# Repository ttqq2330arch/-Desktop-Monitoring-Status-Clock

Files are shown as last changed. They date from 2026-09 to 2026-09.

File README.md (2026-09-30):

# 桌面电脑状态监控 · PC 小屏

ESP32-WROOM-32 DevKit V1（CH340C）+ ST7735S 128×160 横放（逻辑 160×128）。
PC 端采集本机状态 → USB 串口 1Hz 推 JSON → ESP32 负责显示。

三页：**总览 / 大时钟 / 天气**，单个按键 GPIO13 循环切换；PC 在线时三页每 10 秒自动轮播。

**★ 脱离电脑也能当钟用**：设备自带 2.4G WiFi + SNTP 对时，不接电脑时会自动进时钟页
并显示**正确时间**（不再是一块显示「NO DATA」的砖）。配置见「二 · 6 不接电脑也能用」。
总览页与天气页的数据仍来自 PC。

**状态：固件已编译通过（2026-09-19，931,536 B / Flash 70.6% / RAM 16.3%，0 warning；
已删除日历页、新增三页 10 秒自动轮播、新增 WiFi 独立对时）。**

<p align="center">
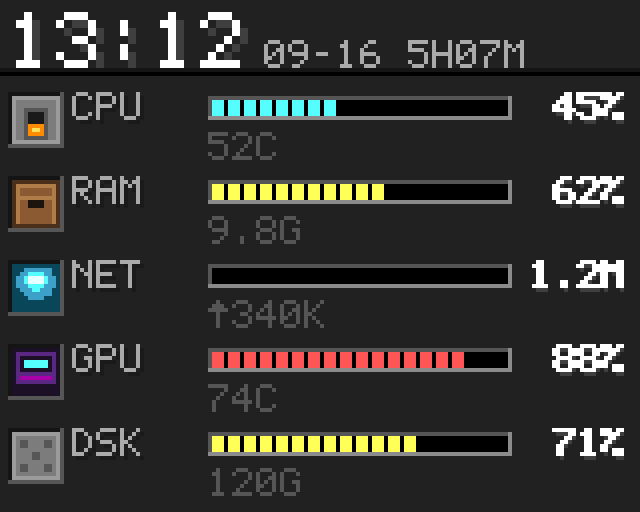
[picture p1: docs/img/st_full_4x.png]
  
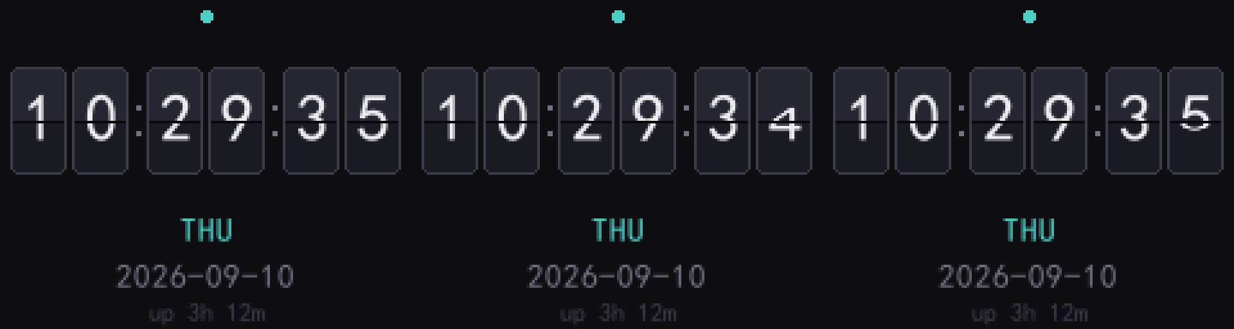
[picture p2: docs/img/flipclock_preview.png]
  
</p>
<p align="center"><sub>
状态页（四环仪表）　｜　翻页时钟
</sub></p>

<p align="center">
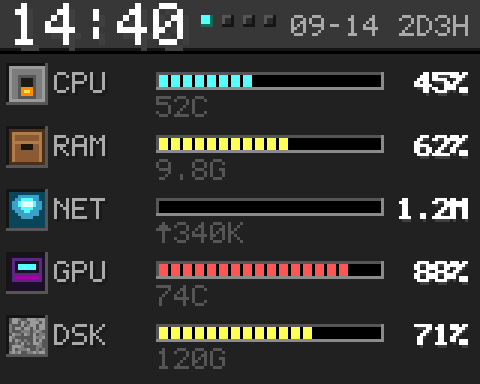
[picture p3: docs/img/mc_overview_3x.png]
  
  
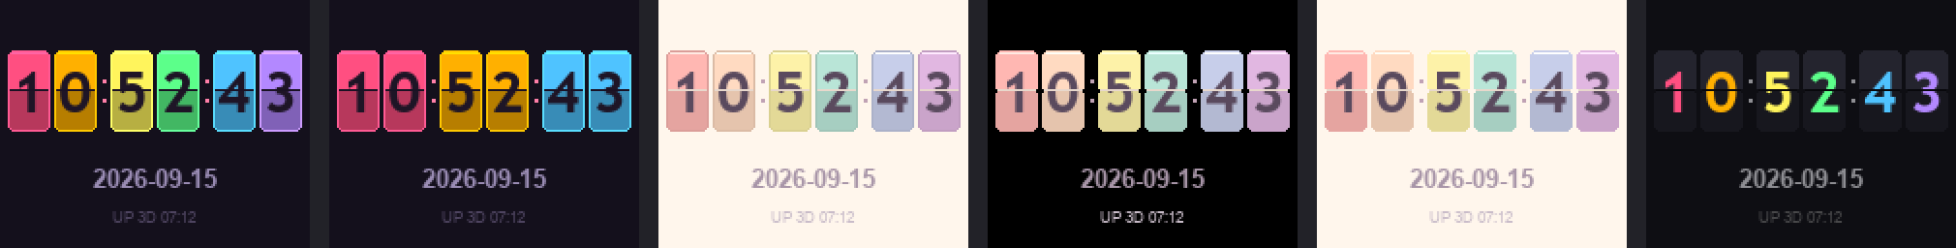
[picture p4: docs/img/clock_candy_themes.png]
  
</p>
<p align="center"><sub>
总览 · 3x 放大　｜　磁盘方块图标细节　｜　时钟配色备选
</sub></p>

更多设计稿在 `docs/img/`，全部由 `esp32/tools/` 下的生成器离线产出。

---

## 一、接线

| ST7735S | ESP32 | 说明 |
|---|---|---|
| VCC | 3.3V | **不要接 5V** |
| GND | GND | |
| SCL / SCK | GPIO18 | VSPI 时钟 |
| SDA / MOSI | GPIO23 | VSPI 数据 |
| CS | GPIO5 | 片选 |
| DC / A0 | GPIO17 | 数据/命令 |
| RES / RST | GPIO16 | 复位 |
| BLK | GPIO4 | 背光，LEDC PWM 调光（默认 78%） |
| MISO | 不接 | |

按键：**GPIO13 → GND**（内部上拉），短按切页（并重置 10 秒轮播计时），长按 >600ms 切换时钟页数字字体。

接线示意图见 [`docs/接线图.svg`](docs/接线图.svg)（SVG，浏览器可直接打开）。

引脚定义在 `esp32/src/main.cpp` 顶部的 `PIN_*`。

> 避开的引脚：6~11（SPI Flash）、34~39（input-only）、0/2/12/15（strapping）。

---

## 二、跑起来

### 1. 编译烧录

```bat
cd esp32
pio run -t upload
```

首次编译会自动下载 LovyanGFX 与 ArduinoJson、PubSubClient（约 130 MB，只需一次）。

**烧录前必须关掉采集脚本**——CH340C 在 DevKit V1 上硬接 UART0，脚本独占 COM 口时
PlatformIO 抢不到端口：

```bat
cd ..\pc
python stop_monitor.py     :: 建 pause.flag + 杀采集进程
```

**不想搭编译环境？** `esp32/firmware_prebuilt/` 里有与源码同版本的固件四件套
（含 md5 与烧写偏移说明），用 esptool 一条命令直烧即可。注意：工程使用**自定义
3MB app 分区表**（`esp32/partitions.csv`，离线局域网轮询的 flash 前提），
无论哪种烧法都必须连 `partitions.bin` 一起烧，单烧 app 会因分区不一致而异常。

### 2. 装依赖并启动采集

```bat
pip install psutil pyserial nvidia-ml-py
cd pc
python monitor.py --list        :: 看串口号
python monitor.py               :: 自动扫 CH340
python monitor.py --port COM6   :: 手动指定
python monitor.py --dry-run     :: 只打印 JSON 不下发，调试用
```

### 3. 开机自启 + USB 看门狗

**插上 USB 就自己跑，不用管时机。** 靠两级配合：

| 层 | 是什么 | 干什么 |
|---|---|---|
| 任务计划 `PCMonitorWatch` | 登录时启动 `watcher.py` | 只负责让看门狗活着 |
| USB 看门狗 `watcher.py` | 常驻，每 3 秒扫一次串口 | 看到 CH340 就把 `monitor.py` 拉起来 |

**为什么不直接让任务计划启动 `monitor.py`**：登录瞬间 USB 常常还没枚举完，
那个时点启动是赌运气。看门狗不看时机看硬件——开机时已经插着、还是后来才插、
拔了再插，它都能接管。

任务计划参数：触发器 `AtLogOn`、错过补跑 `StartWhenAvailable`、
失败重启最多 3 次（间隔 1 分钟）、运行时限无限制、全程无窗口。

**为什么用任务计划而不是注册表 Run 键**：Run 键只能"到点跑一次"，跑了就死了没人管；
任务计划能错过补跑、失败重启，而且进程由 `svchost` 托管，更稳。

实测三条行为（都验过）：

- 采集进程被杀 → 3 秒内看门狗自动拉起，屏 5 秒内恢复
- 拔掉开发板 → 看门狗不动作，`monitor.py` 自己等 USB 回来重连（避免抖动误杀）
- 有 `pause.flag` → 看门狗让路不拉起（烧录用）

其他关键点：

- **用 `pythonw` 而不是 `python`**：GUI 子系统程序，天生没有控制台窗口。
  代价是 `pythonw` 没有 stdout，脚本已内置兜底，把输出写进 `pc/monitor.log`。
- **不要包一层 `cmd.exe /c`**：cmd 是控制台程序，登录时会闪一下黑窗口。
- **不要加 VBS / `wscript` 中间层**：本机安全策略把 `wscript.exe` 当 LOLBin 拦截。
- **脚本自带单实例保护**：已有实例在跑时新启动的直接退出，不会多实例抢同一个串口。
- **判断采集在不在跑用端口锁（47651），不扫进程**——扫进程在 pythonw 下
  会把启动中的自己误判成目标，之前踩过。看门狗自己的锁是 47652。
- 采集起来后屏会在 1 秒内从 `PC MONITOR` 跳到数据界面。

安装 / 卸载（**换电脑、重装系统后跑一次就行**）：

```bat
install.bat                    :: 双击。自动找 Python、装依赖、注册任务、启动
python install.py --check      :: 只体检，不改任何东西
python install.py --uninstall  :: 卸载计划任务
```

`install.py` 会做四件事：找解释器（优先无窗口的 `pythonw`）→ 补依赖
（`psutil` / `pyserial`，缺就自动 `pip install`，装不上会退回 `--user`）
→ 注册计划任务 → 启动并回报任务状态。

**路径全是动态探测的**，没有写死用户名和盘符，拷贝整目录到任何一台 Windows
都能用。看门狗拉起采集脚本时也用自己所在的解释器，不会去找某个固定路径。

日常启停：

```bat
python stop_monitor.py     :: 停止采集（烧录固件前必做）
start_monitor.bat          :: 双击，恢复推送
```

**烧录固件的标准流程**（顺序不能反）：

```bat
python stop_monitor.py     :: 创建 pause.flag + 杀采集进程
pio run -t upload          :: 烧录（此刻 COM 口是空的）
start_monitor.bat          :: 删掉 pause.flag，看门狗几秒内自动恢复推送
```

`stop_monitor.py` 必须先建 `pause.flag` 再杀进程——只杀进程的话，
看门狗 3 秒内就把脚本拉回来，COM 口又被抢走，烧录必然失败。

> 脚本版和便携版**任选一种，别同时装**。便携版的日志在
> `pc\dist\pc-monitor-portable\` 下，不在 `pc\` 下——排查时别翻错目录。

### 4. 换到另一台电脑

ESP32 固件在板上，**不用重烧**。要搬的只有 PC 端。按那台电脑有没有 Python 分两条路。

#### 4A. 没装 Python（推荐，零依赖）—— 用免安装便携版

```bat
:: 1. 把 pc\dist\pc-monitor-portable 整个文件夹拷过去（U 盘都行，约 16 MB）
:: 2. 双击「安装.bat」
:: 3. 插上 ESP32，几秒内屏幕离开 PC MONITOR
```

> `pc/dist/` 不入库（见 `.gitignore`），先用 `build_portable.py` 在本机打一次包。

目录里就这些东西（详细看里面的 `使用说明.txt`）：

| 文件 | 作用 |
|---|---|
| `monitor.exe` | 采集端，每 1 秒把状态推给小屏 |
| `watcher.exe` | 看门狗，每 3 秒扫串口，见到 CH340 就拉起采集端 |
| `安装.bat` / `卸载.bat` | 注册 / 删除计划任务 |
| `暂停采集.bat` / `恢复采集.bat` | 烧录固件前暂停，烧完恢复 |
| `watcher.log` / `monitor.log` | 出问题时先看这两个 |

重新打包（改过脚本之后必须重打，否则 exe 里还是旧逻辑）：

```bat
python build_portable.py     :: 需要 PyInstaller：pip install pyinstaller
```

#### 4B. 装了 Python 3.8+（勾了 Add Python to PATH）—— 用脚本版

```bat
:: 1. 把整个 pc 目录拷过去
:: 2. 双击 install.bat
::    它会自动：找 Python -> 装 psutil/pyserial -> 注册计划任务 -> 启动看门狗
:: 3. 插上 ESP32，几秒内屏幕离开 PC MONITOR
python install.py --check    :: 想先体检就跑这个，不改任何东西
```

两条路共用的几个已处理掉的坑：

- **路径不写死**：原来硬编码了某台机器的 PlatformIO 解释器绝对路径，
  换台机器必然失效。现在脚本版运行时探测解释器，打包版用 exe 自身位置定位。
- **串口号不写死**：自动扫 CH340（VID `1A86`），换台电脑分到 COM3 还是 COM9 都能连。
- **两台电脑别同时插**：板子只有一个串口，两台都跑采集会互相抢。

打包这件事有几个坑，都处理了，重新打包时别改回去：

- **必须用 `--windowed`**：常驻程序不能有控制台窗口，否则桌面一直挂黑框。
  windowed 模式下 `sys.stdout` 为 None，脚本已兜底把输出写进日志文件。
- **日志路径不能用 `__file__`**：打包成单文件 exe 后 `__file__` 指向临时解压目录
  （`_MEIPASS`），日志会写进去然后随进程退出丢失。两个脚本统一用 `app_dir()`——
  frozen 时取 `sys.executable` 所在目录，保证日志落在 exe 旁边。
- **看门狗要直接拉 `monitor.exe`**：打包后没有解释器可调用，`watcher.py` 里
  按 `sys.frozen` 判断，frozen 时执行同目录的 `monitor.exe`。
- **中间产物放纯 ASCII 目录**：`build_portable.py` 把 work/spec 丢到 `%TEMP%`，
  打完再拷回来——中文路径下 PyInstaller 容易出幺蛾子。
- **进程列表里一个实例显示两个 PID**：PyInstaller 单文件模式是「bootloader 父进程
  + 真子进程」，不是双开。脚本版同理（venv 包装器 + 真解释器）。
- **必须用带 PyInstaller 的那个解释器跑**：`build_portable.py` 开头会自检，
  没装 PyInstaller 会直接退出并提示。

### 5. 屏停在 PC MONITOR 怎么排查

`PC MONITOR` 是**等待态**，只说明一件事：ESP32 没收到串口数据。跟屏幕几何、
固件渲染都没关系，别去动 `OFFSET_X/Y`。

按顺序查：

1. **看门狗活着吗** —— 任务 `PCMonitorWatch` 的 `State` 应该是 `Running`，
   用 `schtasks /query /tn PCMonitorWatch` 查；不是就重跑 `install.bat`。
2. **看 `pc/watcher.log`** —— 每 3 秒扫一次，状态变化才记一行：
   - `CH340=未连接` → 线没插好或驱动没装，先看设备管理器。
   - `CH340=COM6 暂停=否 采集=未运行` 却没跟着出现「拉起采集脚本」→ 看门狗卡了，重启任务。
   - `暂停=是` → 有 `pause.flag` 忘了删（烧录后没跑 `start_monitor.bat`）。
3. **看 `pc/monitor.log` 最后几行**：
   - 没有 `[LAUNCH]` 痕迹 → 采集没被拉起，看上一条。
   - 有 `[LAUNCH]` 但没 `[串口] 已连接` → 卡在等 CH340，检查 USB 线和驱动。
   - 有 `[崩溃]` → 下面就是 traceback，照着修。
4. **COM 口被别的程序占了** —— 串口监视器、Arduino IDE 串口绘图仪、`handle64.exe -a Serial` 都能看出来。
5. 烧录固件前必须 `python stop_monitor.py`，否则 PlatformIO 抢不到 COM 口。

### 6. 不接电脑也能用（WiFi 独立对时）

设备插充电头独立供电时，会自动进时钟页并联网取标准时间 —— 不再是「NO DATA」砖。

**首次配置**（只需一次；凭据写进设备 NVS，**不随固件、不进仓库**）：

```
python pc/stop_monitor.py                 # 先让出串口
（用任意串口工具连 COM7 @115200，逐行发送：）
WIFI:你的SSID,你的密码                     # 可发两组（主 / 备用路由器）
NET?                                      # 查看当前状态
```

写完直接拔线插充电头即可。上电 3 秒后开始尝试连接，**拿到时间立刻关掉 WiFi**。

**注意**

- ESP32-WROOM-32 **只支持 2.4G**，路由器的 5G 名字连不上（双频合一通常没问题）。
- 凭据存 NVS，**源码里没有任何 WiFi 密码** —— 这是为 `export_opensource.py` 导出时不泄露。
- 最多记住 2 组，按顺序尝试；换路由器重发 `WIFI:` 即可覆盖；`WIFICLR` 清空全部。
- 没有网络时可用串口手动对时：`TIME:2026-09-19 13:40:00`（重启即失效，仅作兜底）。
- 屏上状态词（时钟页卡片下方）：`NO CFG` 未配置 / `LINKING` 连接中 / `SYNCING` 对时中 /
  `WIFI OK` 已对时 / `NO NET` 连不上 / `NO TIME` 有凭据但还没对上。
- 串口心跳可直接看到设备自己的时间：`[HB] view=1 rx=.. net=WIFI OK t=13:52:03 heap=..`。

---

## 三、屏幕不对，改这几个常量

都在 `esp32/src/main.cpp` 顶部，别的地方不要动。

| 现象 | 改哪个 |
|---|---|
| 有白边 / 画面偏移 | `OFFSET_X`（现 0）、`OFFSET_Y`（现 0） |
| **整屏画面倾斜** | panel 配置里的 `cfg.memory_width`，现 **130**（用库默认 132 就会斜） |
| 红蓝颜色反了 | `RGB_ORDER` → `true` |
| 整屏发黑或发白 | `INVERT_COL` → `true` |
| 花屏 | `SPI_FREQ` 从 `20000000` 降到 `10000000` |
| 屏幕装反了（外壳倒装） | `PANEL_FLIP_180` → `1`（软件逐像素翻转 180°，见下节） |

`cfg.memory_width` 不在顶部常量区，它在 `LGFX` 构造函数的 `_panel.config(cfg)` 块里，
搜 `CFG5` 注释就能找到（那组几何参数是实测轮播挑出来的，别改回默认）。

改完重新 `pio run -t upload`。

### 关于 `PANEL_FLIP_180`（屏幕倒装）

外壳如果把它装反了，把 `PANEL_FLIP_180` 改成 `1` 即可，**别处不用动**。
实现是每帧画完后把整块精灵缓冲做一次逐像素 180° 翻转（行序倒置 + 行内像素倒置），
只搬 16bit 元素、不拆字节，所以 `swap565` 语义不变、不需要额外换字节序。

**为什么不直接用 `setRotation(3)`**：这块 ST7735S 的非标准几何（GRAM 132×162 /
可视 128×160）在 rotation 1 与 rotation 3 下的地址窗口无法对齐，实测两组参数都失败
（先是对角线错位，再是顶部一条乱码）。像素级翻转不触碰地址窗口与 MADCTL，
原理上不会出现错位。

翻转后**逻辑坐标与屏幕视觉是反的**，两件事必须记住：

- 逻辑 y 小 → 物理 y 大 → **屏幕视觉的下方**。屏幕最下方同时是 SPI 写入起点与
  面板扫描起点，两者同向同速，1Hz 整屏刷新时这一带撕裂最重。
- 所以：**每秒变化的高对比内容（时钟、日期）绝不能放在逻辑顶边**。
  两端各留一条静态纯背景带（`EDGE_TOP` / `EDGE_BOT`）就是为了这个——
  端点行每帧恒定，撕裂发生在端点也看不见。
- 幕布过渡要画在**逻辑右侧**，屏上才出现在左侧。

别试图用"每帧把端点行涂成背景色/复制邻行"来补——试过两版都反而露出横线或
把图标底行搬进撕裂带。**结构上留出静态带是唯一可靠的解法。**

---

## 四、显示内容

三页，**单个按键 GPIO13** 循环切换，或 **PC 在线时每 10 秒自动轮播**（切后在本页停留 10 秒，三页循环）。170ms 幕布过渡、1s 刷新、静态不闪烁。

> 自动轮播只在 **PC 在线**时生效。PC 关机 / 断流超过 5 秒后停在时钟页当钟用，不再轮播
> —— 否则会轮流停在总览 / 天气页显示「未连接」。手动短按切页会把 10 秒计时清零重算。

| 页 | 内容 |
|---|---|
| 0 OVERVIEW | 四环仪表：CPU / RAM / NET / GPU 四环 + 顶部时钟 + 右侧日期（蓝=正常，≥80% 整环转红） |
| 1 CLOCK | 彩虹电子时钟：六位糖果色数字 + 日期 + 开机时长；PC 断流 5s 后离线自走时 |
| 2 WEATHER | 城市 + 彩虹环温（弧长=当日高低温区间位置）+ 环内糖果温度 + 高低温 / 湿度 / 风速 |

> 原「整面月视图」日历页已于 2026-09-19 删除（页面数 4 → 3）。

顶栏：时间 + 日期 + 开机时长 + 页码方块。断流 5 秒后日期区显示 `OFF`。

### 1 · 总览页（《我的世界》主题）

色值与结构取自 MC 的 GUI 设计语言：16 色格式化调色板、GUI 灰阶、经验条绿 `#80FF20`。
三条结构规则比色值更关键——**立体边框**（凸=上/左亮、下/右暗；凹反过来）、
**文字右下 1px 投影**、**方块图标嵌物品栏凹槽**。

| 行 | 方块图标 | 条色 | 主值 | 副值 |
|---|---|---|---|---|
| CPU | 熔炉（石框 + 橙火） | §b 青 | 占用 % | 温度 |
| RAM | 箱子（棕木 + 锁扣） | §6 金 | 占用 % | 已用 GB |
| NET | 信标（青宝石） | §9 蓝 | ↓下行速率 | ↑上行速率 |
| GPU | 附魔台（紫 + 符文） | §d 品红 | 占用 % | 温度 |
| DSK | 石头（石块纹理） | §a 绿 | 占用 % | 剩余 GB |

字体是 **5×7 点阵（44 字形）**，本页内容全 ASCII，**不需要中文字库**——
比下面那几套汉字字模轻得多。数据链路：

```
tools/mc_ui_preview.py   设计稿生成器（零第三方依赖，出 1x / 3x / 局部放大 / 字形表 PNG）
        │  import
        ▼
tools/gen_mc_theme.py    导出 src/mc_theme.h（PROGMEM 位图 + 绘制函数），
        │                自带「写出的 C 文本重新解析回来逐值比对」校验
        ▼
   src/mc_theme.h        5×7 字形 / 12×12 方块图标 / mcStr / mcBevel / mcXpBar
```

改设计稿后重跑 `gen_mc_theme.py` 即可（`python gen_mc_theme.py`，日志落 `gen_mc_theme.log`），
**不要手改 `mc_theme.h`**，否则下次生成会覆盖。

排版验证另有一个只读工具 `tools/st_layout_preview.py`：用与固件相同的常量
（`EDGE_TOP` / `BODY_TOP` / `ROW_H`）重画一遍状态页，改版式前先看它，4x 放大出图。

### 2 · 中文点阵字库（天气页用）

内置字体无中文，三套互相隔离的 PROGMEM 字模（都是 SimHei 16×16 生成，
**仓库只含生成出的位图数组，不含字体文件**，见 `THIRD_PARTY.md`）：

| 文件 | 字数 | 生成脚本 | 用途 |
|---|---|---|---|
| `src/cn_font.h` | 12 | `tools/gen_cnfont.py` | **已停用**（原日历标题 年 / 月 / 一~十）；文件保留备用 |
| `src/weather_cn.h` | 34 | `tools/gen_weather_cn.py` | 天气词（晴 / 阴 / 雨 / 高 / 低 / 湿…） |
| `src/cn_city.h` | 199 | `tools/gen_city_cn.py` | 城市地名（省会 + 主要地级市 + 汉江/秦巴一带） |

排版铁律：双字标签占 2×(16+2)=36px，必须用 `cnStrW()` **真测宽**推进——
按单字宽 18px 推会让数字压在字上。字库缺字时 `wcnFind` 返 -1，整段不渲染。

**CPU 温度默认 `--`**：Windows 上没有管理员权限读不到，代价不值。
想开的话：`python monitor.py --temp`，需要管理员 + 把 `LibreHardwareMonitorLib.dll`
放到脚本同目录。

**GPU 非 N 卡显示 `--`**：A 卡和 Intel 核显在 Windows 上没有干净的读取接口。

### 3 · 时钟页（含离线走时）

HH MM SS 六张卡片式数字，每位数从 Candy Rainbow 调色板依次取色，
翻页动画由 `gStretch` 控制拉伸程度。

数字不是内置字体，而是 **4-bit alpha 掩码**（0..15 覆盖度），由
`tools/gen_clock_font.py` 用「超采样 SS=4 渲染 → 形态学膨胀加粗 → LANCZOS 降采样
→ 4bit 量化」烘焙而来——加粗做在超采样大图上，所以加粗后边缘仍然抗锯齿。
内置 4 套字体，**长按按键 >600ms 现场切换**。改字体或粗细后重跑生成器，
它自带触边自检（数字左右必须各留 ≥1px，否则报 `⚠`）。

**离线走时 + 自动对时**：PC 关机 / 断流超过 5 秒，设备自动跳到时钟页当钟用。
时间来源按优先级三级（配置见「二 · 6 不接电脑也能用」）：

1. **PC 在线** —— 串口每帧带真实时间，逐帧对齐，零漂移；
2. **PC 不在线** —— 设备自己连 2.4G WiFi 走 SNTP 取一次标准时间，之后由内部时钟自走，
   每 6 小时重校一次（**拿到时间立刻关 WiFi**，不干扰 SPI 刷屏、也不费电）；
3. **取不到时间** —— 继续用内部时钟，屏上给出状态词（`NO NET` / `NO CFG`）。

内部走时取决于 ESP32 的 40MHz 晶振（±10~40ppm），一天偏差数秒内，看时间够用。
**从来没有时间源**时（刚上电且未联网），时钟页显示六张空卡片 + 横杠占位 + 状态词，
不会退化成一块「NO DATA」。

### 4 · 天气页

`pc/monitor.py` 在 PC 侧拉天气，把结果随状态一起推进固件 —— 天气数据始终由 PC 提供。
（ESP32 自身只在「没有 PC 时间源」时短暂联网做 NTP 对时，不负责抓天气。）

配置在 `pc/weather_tune.json`（仓库给的是 `weather_tune.example.json`，
复制改名即可），可写死城市，也可以 `auto_location` 走 IP 定位。

几个已经踩过的坑，改这块前先读：

- **中文城市名与坐标必须同源。** 先用国内源（pconline）拿到中文城市名，
  再用 Open-Meteo 的 geocode 取该城市的坐标；`ipinfo.io` 只做兜底，
  且它的英文名必须能被内置 `CITY_ZH` 表识别才采纳其坐标。
  早期把「ipinfo 的坐标 + pconline 的中文名」拼在一起，屏上显示出「安康」
  而温度是另一个城市的——地名和天气对不上，就是这么来的。
- **网络出口直连优先。** 如果系统装了代理软件但没启动，
  Windows 下 `urllib.getproxies()` 会读到注册表里的代理地址，
  把所有请求发往一个没人监听的端口，四个天气源会全挂。
  `monitor.py` 里 `_open()` 显式用 `ProxyHandler({})` 先直连、失败才回落代理，
  日志会打一行 `[天气] 网络出口：直连`。
- **结果落盘缓存** `weather_cache.json`：看门狗重启 monitor 时先用缓存顶住，
  断网也不至于显示「无数据」。
- **失败退避重试** 30s→60s→…→300s，开机时网络往往还没就绪，这一步很关键。
- **城市名回退字段必须是纯 ASCII**：设备端中文缺字时用 ASCII 字库渲染它，
  所以 `monitor.py` 会用 `CITY_EN` 把中文城市名转成拼音（安康 → ANKANG）。

### 5 · 打印机页 ×2（双源：串口 / 局域网直连，互不干涉）

第 4、5 页显示两台 3D 打印机的实时状态（热端/热床温度、打印进度、文件名）。
数据来源由「PC 是否在线」单一门控，两路天然互斥：

- **PC 在线** → 走串口：`pc/printers.py` 在 PC 侧轮询打印机，随状态帧一起推给固件。
  Creality 走局域网 Moonraker（:7125），Anycubic 走打印机局域网 MQTT
  （Kobra X :18910 发现 → :9883 MQTT-TLS，凭据 AES-128-CBC 解密）。
- **PC 离线** → 固件自己用 WiFi 直连打印机（`src/printerlan.cpp`），
  打印机页照常显示，屏幕在「时钟 + 已配置打印机页」间轮播。

打印机 IP 配置三入口（NVS 断电保留）：

1. 串口命令：`PRN:槽位,类型,IP[,名称]`（槽 0=Creality/类型 0，槽 1=Anycubic/类型 1）、
   `PRNCLR` 清空、`PRN?` 查询；
2. 设备网页配置页「离线局域网打印机」卡片；
3. 已存 NVS 时断电重启自动生效。

设备状态接口 `http://<设备IP>/api/status` 里每台打印机带 `"src": "PC"/"LAN"`
字段，可直接验证当前数据来源。

---

## 五、仓库结构

```
esp32/
  platformio.ini          工程配置（依赖走 lib_deps 自动下载）
  partitions.csv          自定义分区表：app 3MB（离线 LAN 轮询的 flash 前提）
  no_map.py               摘掉 -Wl,-Map，绕开中文路径导致链接失败（见第七节）
  firmware_prebuilt/      预编译固件四件套（免编译直烧，含 md5 与偏移说明）
  src/
    main.cpp              固件全部逻辑（五页渲染 / 按键 / 串口协议 / 翻转）
    printerlan.h/.cpp     双源架构：PC 离线时 WiFi 直连打印机（Moonraker / MQTT-TLS-AES）
    mc_theme.h            总览页点阵字与方块图标（生成物，勿手改）
    clock_fonts.h         时钟页 4-bit alpha 数字掩码（生成物，勿手改）
    cn_font.h             中文点阵字模（已停用，保留备用）
    weather_cn.h          中文点阵字模 —— 天气词
    cn_city.h             中文点阵字模 —— 城市名
    netclock.h/.cpp       独立对时：WiFi + SNTP，凭据存 NVS（不接电脑也能当钟用）
  tools/                  离线工具（生成器 / 仿真 / 硬件探针）
    gen_mc_theme.py       总览页主题 → mc_theme.h
    gen_clock_font.py     时钟数字掩码 → clock_fonts.h
    gen_cnfont.py         字模生成器 → cn_font.h（当前未参与编译）
    gen_weather_cn.py     天气词字模 → weather_cn.h
    gen_city_cn.py        城市名字模 → cn_city.h
    mc_ui_preview.py      总览页设计稿（gen_mc_theme.py 的数据源）
    st_layout_preview.py  状态页排版验证（4x 出图）
    probe_diag.py         硬复位 + 注帧 + 读心跳，区分「没收到」与「解析失败」
    _verify_rotation.py   运行期验证三页 10 秒自动轮播（注帧保活 + 记录 [HB] view 序列）
    _sim_netclock.py      对时状态机 PC 端仿真（超时/退避/重校窗口，27 条断言）
    _verify_offline_clock.py  运行期验证「脱离电脑自己取到时间」（停 monitor + 硬复位 + 采样）
    _diag_flash_fail.py   烧录失败排查（端口占用 / 目录完整性 / flash.exe 完整输出）
    probe_boot.py / probe_frame.py / read_glyph_debug.py
  tools/fonts/            时钟页用的 OFL 字体（Trebuchet MS 不在其中）
pc/
  monitor.py              PC 端采集，1Hz 推 JSON
  watcher.py              USB 看门狗
  install.py / install.bat          安装与卸载计划任务
  stop_monitor.py / start_monitor.bat
  build_portable.py       打包免安装便携版（需要 PyInstaller）
  flash.py                串口烧录辅助
  test_pipeline.py        端到端自检
  weather_tune.example.json         天气配置模板
docs/
  接线图.svg
  img/                    精选设计稿（生成器产出的原图在 esp32/tools/，不入库）
licenses/                 随仓库分发的字体许可全文（OFL 1.1）
```

---

## 六、依赖与许可

本项目代码以 **MIT** 发布，见 `LICENSE`。
第三方组件（LovyanGFX FreeBSD / ArduinoJson MIT / 三套 OFL 字体 / 不收录的商业字体 /
《我的世界》风格声明）逐项列在 **`THIRD_PARTY.md`**，上手前建议扫一眼。

一句话总结：**仓库不含任何第三方库源码、不含商业字体、不含打包产物**，
`pio run` 会自动补齐依赖，字体许可全文在 `licenses/`。

---

## 七、开发环境备注

### 1. 中文路径的坑（已绕过）

工程目录如果含中文，xtensa 链接器无法在非 ASCII 路径创建 `firmware.map`，链接会失败。
`esp32/no_map.py` 摘掉了 `-Wl,-Map` 参数来解决。

**根治**：把项目搬到纯 ASCII 路径（比如 `F:\pc-monitor`），
然后删掉 `platformio.ini` 里的 `extra_scripts = no_map.py` 和 `no_map.py` 本身。

### 2. 为什么锁 `espressif32@6.12.0`

不锁版本时平台每次都会联网查 registry，网差时卡住。锁定后行为可复现。
换平台版本要注意：`tool-scons` 需要 **4.41101.0**（`6.12.0` 的要求），
低版本的 ESP8266 老项目可能得把目录名换回去。

### 3. 改完代码记得重新生成

`mc_theme.h` / `clock_fonts.h` / 三套中文字模都是**生成物**。
改了 `tools/` 下的设计稿或字表，要重跑对应生成器再编译——
手改这些 `.h` 会在下次生成时被覆盖。

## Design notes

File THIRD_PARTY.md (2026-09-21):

# 第三方资源与许可

本仓库**只收录自己写的代码与生成结果**，第三方库、商业字体、打包产物均不入库。
下面逐项说明每一项的来源、许可与处置方式。

---

## 1. 固件依赖（由 PlatformIO 自动下载，仓库不含源码）

| 组件 | 版本 | 许可 | 说明 |
|---|---|---|---|
| [LovyanGFX](https://github.com/lovyan03/LovyanGFX) | `^1.2.0` | **FreeBSD** | LCD 驱动与精灵缓冲。库内还打包了若干子组件，各有独立许可（TJpgDec / Pngle MIT / GFX font 2-clause BSD / IPA font 等），详见上游仓库的 License 段落 |
| [ArduinoJson](https://github.com/bblanchon/ArduinoJson) | `^7.1.0` | **MIT** | 串口 JSON 解析 |
| [espressif32 platform](https://github.com/platformio/platform-espressif32) | `6.12.0` | Apache-2.0 | PlatformIO 平台定义 |
| Arduino core for ESP32 / ESP-IDF | 随平台 | Apache-2.0 / LGPL-2.1 | 由上面的平台自动拉取 |

原开发机上这些库曾放在 `esp32/lib/`（共约 130 MB）离线编译。
开源版已在 `platformio.ini` 里改用 `lib_deps`，首次 `pio run` 时自动下载，**仓库不需要也不应该包含 `lib/`**。

---

## 2. 字体

### 2.1 随仓库分发（SIL Open Font License 1.1）

翻页时钟的数字掩码由 `esp32/tools/gen_clock_font.py` 离线烘焙而来。
其中三套字体是 Google Fonts 发布的 OFL 字体，**随仓库提供**，许可全文见 `licenses/`：

| 文件 | 版权行 | 许可全文 |
|---|---|---|
| `esp32/tools/fonts/Fredoka_wdth_wght.ttf` | Copyright 2016 The Fredoka Project Authors | `licenses/OFL-Fredoka.txt` |
| `esp32/tools/fonts/Nunito_wght.ttf` | Copyright 2014 The Nunito Project Authors | `licenses/OFL-Nunito.txt` |
| `esp32/tools/fonts/Poppins-Bold.ttf` | Copyright 2020 The Poppins Project Authors | `licenses/OFL-Poppins.txt` |

这三套字体另有 6 个同批次的选型候选字体（Asap / Baloo 2 / Comfortaa / Quicksand /
Varela Round / M PLUS Rounded 1c）在选型阶段被淘汰，**未收录**，以控制仓库体积。

### 2.2 不随仓库分发（专有 / 商业授权）

| 字体 | 用在哪 | 为什么不收录 |
|---|---|---|
| **Trebuchet MS**（`C:/Windows/Fonts/trebucbd.ttf`） | 时钟第 4 套数字 | Microsoft 随 Windows 分发的商业字体，**无再分发授权**。脚本从本机系统字体读取，因此仓库不含该文件 |
| **SimHei 中易黑体** | 生成 16×16 中文点阵字模（`src/cn_font.h` / `weather_cn.h` / `cn_city.h`） | 同样是 Microsoft 专有字体。仓库收录的是**从字体渲染出的位图数组**，不含字体文件本体 |

`gen_clock_font.py` 已做容错：**字体文件不存在时自动跳过并打印提示**，
所以在没有 Trebuchet MS 的机器（或 Linux / macOS）上重新生成仍是可用的，只是少一套字形。

想要凑齐 4 套：把你系统里对应的字体放到 `esp32/tools/fonts/` 并改 `FONTS` 表的路径即可。

---

## 3. 视觉风格参考：《我的世界》

总览页（`src/mc_theme.h`）的配色、立体边框、经验条等**取自《我的世界》(Minecraft)** 的
GUI 设计语言，属于风格致敬：

- 本仓库**不包含**任何 Mojang / Microsoft 的美术资源文件（无贴图、无音效、无字体）。
- 所有图标都是在代码里用矩形与像素点**重新画**出来的（见 `tools/mc_ui_preview.py`）。
- 本项目与 Mojang Studios / Microsoft **无任何关联**，未获其赞助或认可。
- "Minecraft" 是 Mojang Synergies AB 的商标。

若你要把这个项目用于商业用途，建议把总览页换成中性配色（`main.cpp` 里的 `MC_*` 常量集中可改），
以规避商标与外观风格方面的争议。

---

## 4. USB 转串口驱动（CH340 / CH341）

本仓库在 `drivers/CH340/` 下附带 **WCH（南京沁恒微电子）官方的 CH341SER 驱动**，
用于 Windows 上识别板载的 CH340C USB 转串口芯片。目录内容：

- `CH341SER.EXE` —— WCH 官方安装程序（兜底，双击或 `CH341SER.EXE /S` 静默安装）
- `install_driver.bat` —— **一键安装脚本（推荐）**：以管理员运行后，用 `pnputil` 把驱动
  预注册进系统驱动库，**之后任何 CH340 板子插上都会自动匹配，零点击**
- `raw/` —— 从本机已验证系统提取的原始驱动文件（`ch341ser.inf` / `CH341S64.SYS` /
  `CH341SER.CAT` / `CH341PT.DLL` / `CH341PTA64.DLL` / `CH341PORTSA64.DLL`，均带 WHQL
  微软交叉签名），供 `pnputil` 预注册使用；与 `CH341SER.EXE` 同属 WCH 驱动，许可一致
- `安装说明.txt` —— 简短安装提示（已并入 `README.md`，保留兼容）

- **为什么带它**：很多人的电脑没有预装该驱动，插上开发板后设备管理器里只会显示
  带黄色感叹号的未知设备，串口都认不出，自然跑不起来。带上驱动能让 clone 下来的人
  **双击 `CH341SER.EXE` 或用 `install_driver.bat` 一键预注册就识别**，免去到处找驱动的麻烦。
- **许可**：CH341SER 是 WCH 的专有驱动软件，随其 USB 转串口芯片免费分发，
  用于让芯片在主机上正常工作。具体许可条款以安装包内自带说明为准。本仓库仅作
  **随硬件分发的便利副本**提供，不包含任何修改。
- `CH340` 与 `CH341` 驱动通用（文件名虽是 CH341SER，CH340 开发板同样适用）。
- 如果你在 Linux / macOS 上使用，不需要这个驱动（系统内核自带 ch341 / cp210x 支持），
  本节可忽略。

---

## 5. 未收录的运行时产物

为了保持仓库干净，下列内容一律不入库（已写入 `.gitignore`）：

| 内容 | 原因 |
|---|---|
| `esp32/.pio/` | PlatformIO 编译缓存（170 MB+），本地可重建 |
| `esp32/lib/` | 第三方库源码，改由 `lib_deps` 拉取 |
| `pc/dist/` | PyInstaller 便携版产物（3 个 exe，30 MB+），可用 `pc/build_portable.py` 重新打包 |
| `*.log` / `build_log.txt` / `probe_log.txt` | 运行与调试日志 |
| `pc/weather_tune.json` | 本机运行配置，仓库给的是 `weather_tune.example.json` |
| `esp32/src/clock_font.h` | 单字体时代的残留文件，固件已改用 `clock_fonts.h` |
| `esp32/tools/*.png` | 设计稿生成器的中间产物；精选图另存于 `docs/img/` |

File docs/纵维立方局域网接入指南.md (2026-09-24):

# 纵维立方（Anycubic）打印机局域网接入指南

> 适用：Kobra 2 / 2 Pro / X / 3 等带「局域网模式」的机型。
> 特点：**全程不需要账号密码**——凭据由程序自动向打印机索取，接上就能用。

---

## 一、接入三步（5 分钟搞定）

| 步骤 | 操作 | 说明 |
|---|---|---|
| ① 开局域网模式 | 打印机屏幕：**设置 → 局域网模式 / LAN 模式**，打开开关 | 开一次即持久生效；开启后可能掉出云端 App，属正常现象 |
| ② 查打印机 IP | 打印机屏幕网络信息页，或登录路由器看设备列表 | 例：`192.168.1.16` |
| ③ 填配置 | 把 `pc/printers.json.example` 复制为同目录 `printers.json`，改 printer2 的 `ip` 和 `name` | 只填这两项，其余不动 |

改完重启采集程序（或重启电脑），屏幕打印机页 / 手机网页即显示实时状态。**没有第 4 步。**

```json
"printer2": {
  "enabled": true,
  "type": "anycubic_lan",
  "name": "Kobra X",        // 随便起名，屏幕顶栏显示（英文/数字）
  "ip": "192.168.1.16"      // ← 换成你打印机的 IP
}
```

---

## 二、"上电即连"是怎么做到的

程序**不预存任何凭据**，每次启动现场向打印机索取：

```
打印机上电（已开局域网模式）
   │
   ├─ GET  http://<ip>:18910/info          → 拿临时 token（明文 HTTP，免签名）
   ├─ POST /ctrl?ts&nonce&sign&did         → AES 密文（sign=MD5 链，密钥取自 token）
   ├─ 解密 → MQTT 账号/密码 + 客户端证书    ← 全自动，人不用碰
   └─ mqtts://<ip>:9883 连上，订阅 anycubic/#
```

连上之后两条数据通道并行：

| 通道 | 方式 | 内容 | 频率 |
|---|---|---|---|
| 进度/层数/文件名 | 打印机**事件推送** | `.../print/report` | 约 1 分钟 / 状态变化时 |
| 温度/风扇/状态 | 程序**主动查询** | `.../info` → 回复带热端/热床温度 | 每 30 秒 |

**断线自愈**：打印机断电再上电、网络闪断，程序按 3→6→12→…→60 秒退避自动重连，
重连时**重新发现凭据**（token 是一次性的，重发现是必须的）。人无需任何操作。

协议出处：Rinkhals 社区对 Anycubic 固件 MQTT 协议的逆向文档
（`rinkhals-community.github.io/Rinkhals/firmware/mqtt`）。

---

## 三、稳定运行的两个建议

1. **给打印机绑固定 IP**（重要）：路由器管理页 → DHCP 静态绑定，把打印机 MAC 绑到固定 IP。
   IP 一变程序就找不到了（凭据、证书都跟着 IP 走）。
2. **别开"仅云端"再切回来**：局域网模式开着时云端 App 看不到机器是正常的，两套通道二选一。

---

## 四、排错速查

| 现象 | 原因 | 处理 |
|---|---|---|
| 屏幕一直「无连接」 | 局域网模式没开 | 打印机屏幕检查开关 |
| 之前能用突然断了 | 打印机 IP 变了 | 路由器重新查 IP / 绑定静态 IP |
| 日志刷 `链路异常...重试` | 打印机刚上电还在启动 | 等它完全开机，1 分钟内自动接上 |
| 进度有、温度 `--` | 刚连上还没到查询点 | 最多等 30 秒 |
| 想手动验证链路 | — | `python pc/printers.py --dump`（源码工程内） |

---

## 五、代码位置（开发者）

| 文件 | 内容 |
|---|---|
| `pc/printers.py` → `AnycubicLAN` | 凭据发现（含纯 Python AES-128-CBC）+ MQTT 会话 + 主动查询线程 |
| `pc/printers.json(.example)` | 配置（真实文件含内网地址，不进仓库） |
| `tools/_anycubic_lan.py` | 独立诊断脚本（探测端口→取凭据→连 MQTT→监听） |
| `tools/_kx_query_info.py` | 单次温度查询验证脚本 |
| `esp32/src/main.cpp` → `drawPrinterPage` | 屏幕绘制（打印机页） |

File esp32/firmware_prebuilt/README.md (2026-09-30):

# 预编译固件（免编译直烧）

与仓库源码同版本构建的固件四件套，不想搭 PlatformIO 环境可直接用 esptool 烧录：

```bash
python -m esptool --chip esp32 --port COM5 --baud 921600 \
  --before default_reset --after hard_reset write_flash -z \
  --flash_mode dio --flash_freq 40m --flash_size 4MB \
  0x1000 bootloader.bin 0x8000 partitions.bin 0xe000 boot_app0.bin 0x10000 firmware.bin
```

注意：本固件使用仓库自带的**自定义 3MB app 分区表**（`esp32/partitions.csv`），
必须连 `partitions.bin` 一起烧，单烧 app 会因分区不一致而异常。

| 文件 | 烧写偏移 | 字节 | md5 |
|---|---|---|---|
| `bootloader.bin` | 0x1000 | 17536 | `70c9a76fcbc41d62b871521885c08342` |
| `partitions.bin` | 0x8000 | 3072 | `aa5fc164aaabbe6bb8a19f52e2752cf3` |
| `boot_app0.bin` | 0xe000 | 8192 | `e6327541e2dc394ca2c3b3280ac0f39f` |
| `firmware.bin` | 0x10000 | 1207312 | `abfb0fd7f7e43f818e2e0e7a7c01a684` |

串口号以设备管理器为准（CH340）；请先停掉 PC 采集端再烧（`pc/stop_monitor.py`）。
说明：固件内嵌的调试串包含构建机路径（Administrator 为 Windows 默认账户名，非机密），
由 ESP-IDF 头文件的 assert 宏引入，不影响功能与安全。

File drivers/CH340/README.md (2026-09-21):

# CH340 / CH341 USB 转串口驱动

开发板使用 **CH340**（USB 转串口）芯片。第一次在陌生电脑上插板子时，如果系统没装过驱动，
设备管理器会显示带黄色叹号的「未知设备」，串口无法识别，固件端也就扫不到 COM 口。

本目录提供安装驱动的文件，**推荐用一键脚本**：

## 方式一（推荐）：一键自安装脚本
1. 进入本目录，右键 `install_driver.bat` → **「以管理员身份运行」**
2. 脚本会把驱动 **预注册进系统驱动库**（`pnputil /add-driver ... /install`）
3. 之后 **任何 CH340 板子插上都会自动匹配驱动**，不再需要手动安装

> 为什么必须管理员？把驱动写进系统驱动库是受保护操作。
> 若系统没有 `pnputil`（很老的 Windows），脚本会自动改用 `CH341SER.EXE` 静默安装。

## 方式二：官方安装程序
直接双击 `CH341SER.EXE`，按向导点「安装」即可。命令行静默安装：`CH341SER.EXE /S`。

## 验证是否成功
插上板子，打开「设备管理器 → 端口 (COM 和 LPT)」，应出现形如 `USB-SERIAL CH340 (COMx)` 的条目。
固件端会自动扫描 CH340 所在 COM 口，无需手动指定。

## 文件说明
- `install_driver.bat` —— 一键安装脚本（推荐）
- `CH341SER.EXE` —— WCH 官方驱动安装程序（兜底）
- `raw/` —— 从已验证系统提取的原始驱动文件（inf/sys/cat/dll，带 WHQL 签名），供 `pnputil` 预注册使用
- `README.md` —— 本说明

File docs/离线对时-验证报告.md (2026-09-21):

# 离线对时（netclock）真机验证报告

日期：2026-09-20 09:05–09:16 ｜ 设备：ESP32-WROOM-32 DevKit V1 + ST7735S 128×160（COM7）
脚本：`esp32/tools/_verify_offline_clock.py --netsh tt112233`
固件：`firmware.bin` **931600 B**，md5 `30e6784fedbb34acb3d0df0326652c60`（Flash 70.6% / RAM 16.3%）

## 一、要验的是什么

设备**不接电脑**（插充电头）时，时钟页能不能自己拿到并显示正确时间。

之前的行为：设备只有收到 PC 推的 JSON 才会置 `gClkSynced`，不接电脑就**没有时间源**，
时钟页只会画 `NO DATA` —— 这不是显示 bug，是当时确实没时间。

现方案（`src/netclock.h/.cpp`）：PC 在线时完全不碰 WiFi；只有在**没有 PC 时间源**时才连
WiFi + SNTP 取一次；取到后**立刻 `WiFi.mode(WIFI_OFF)`**，成功一次 **6 小时**内不再重校。
WiFi 凭据只存 **NVS**，绝不进源码（本工程要开源导出）。

## 二、怎么模拟"脱离电脑"

真机脚本按顺序做：

1. 落 `pause.flag` + `schtasks /change /disable /tn PCMonitor` + `taskkill monitor.exe`
   → **让设备彻底失去 PC 数据源**
   （★必须连计划任务一起禁用：任务带 `-RestartCount 3`，光杀进程 1 分钟内会被拉起并抢走 COM 口）
2. 串口写入 WiFi 凭据 `WIFI:tt112233,***`（密码从本机 `netsh wlan show profile … key=clear` 读，
   **不落文件、不打印**）
3. **硬复位**（`RTS` 拉低再放开）→ RAM 清空、无任何时间源 = **等价于「插上充电头刚通电」**
4. 抓 60 秒串口日志
5. 恢复采集（删 flag + enable/run 计划任务）

## 三、结果：PASS

| 判据 | 实测 | 结论 |
|---|---|---|
| 凭据存住 NVS（复位后仍可读） | `[NET] begin creds=1` | ✅ |
| 主动联网成功 | `[NET] connected ip=192.168.1.37 rssi=-61` | ✅ |
| 自己对时且时间正确 | `SNTP ok 2026-09-20 09:14:48`，与**对时那一刻**的 PC 时间差 **0.6 s** | ✅ |
| 拿到时间后关射频 | `[NET] wifi off`（9.9 s 处） | ✅ |
| 心跳带时间且持续推进 | `[HB] net=WIFI OK t=…` 每 3 s 一条，末条与当时真实时间差 **1.4 s** | ✅ |
| 独立上电**开机即时钟页** | `[HB] view=1` 从**首拍（3.5 s）起就出现**，`gFirstOnlineDone` 在收到 PC 首帧才升级总览 | ✅ |
| 离线不轮播、不闪总览 | 全程 `出现过的页:[1]`（无任何总览/天气闪过） | ✅ |

时间线（复位后秒数）：

```
 1.4s  [NET] begin creds=1              ← 凭据从 NVS 读出来了
 3.5s  [HB] view=1 ... net=NO TIME      ← ★开机第一拍就是时钟页（只插电源不开机直接是钟，0 闪屏）
 4.6s  [NET] connecting slot=1 ssid=tt112233
 6.5s  [HB] view=1 ... net=LINKING
 8.5s  [NET] connected ip=192.168.1.37 rssi=-55
 9.5s  [HB] view=1 ... net=SYNCING
12.3s  [NET] SNTP ok 2026-09-20 10:04:31
12.3s  [NET] wifi off                   ← 拿到时间立刻关射频
12.5s  [HB] view=1 ... net=WIFI OK t=10:04:31
57.5s  [HB] view=1 ... net=WIFI OK t=10:05:16   ← 与真实时间差 0.7s
```

> 注：上面是 2026-09-20 第二次验证（开机即时钟页版）的时间线。第一次验证（06 节之前的版本）
> 因为是「6 秒门限后才跳钟、期间闪总览」，页序列是 `0 → 1`；改完后在离线场景全程 `[1]`。

内存观察：`heap` 248880 → 连上 WiFi 后跌到 198560 → 关射频后回升 **231984**
（net80211 保留约 17 KB，可接受）。

## 四、过程中修掉的两个问题

### 1. 验证脚本自身误报（已修）

第一次跑报 `设备时间与 PC 相差 57.5s`，**那是脚本的锅**：57.5 s 正好等于
「SNTP 成功」到「脚本跑完」的采样时长 —— 脚本拿 **10.7 s 时刻取到的设备时间**去比
**脚本结束时（60 s 后）的 `datetime.now()`**，差值里混进了采样时长。
设备其实只差约 1 秒。

修法：采样起点记 `wall0 = datetime.now()`，把日志行的时间还原为
`当时PC时间 = wall0 + 该行相对秒数`，再比。改完后 `0.6 s / 1.4 s`，真实差异立刻显形。

> **通用铁律**：时间戳类判据必须把两侧对齐到「同一时刻」；另外，判据所依赖的现象
> 必须在被测固件里**有对应日志**（否则判据永远不成立）。

### 2. 烧录脚本隐患（已修）

`tools/_do_flash.py` 末尾"兜底拉起 monitor"指向 `pc/dist`（**构建输出**），
会与桌面部署那份同时跑、抢 COM 口。已改为优先拉桌面部署份。

### 3. 追加需求：只插电源不开机，一开机就是钟（已修 + 已验）

用户追加："没有连接电脑只是给他接上电源让它自动跳转时钟！"

第一轮实现是「6 秒门限后才跳钟、期间闪总览」——用户要的是**插电直接是钟、0 闪屏**。

- 改法：`curView` 初值 `VIEW_CLOCK`；新增 `gFirstOnlineDone`，**只有收到 PC 首帧**才升级到总览页
  （插着电脑约 1 秒后自然切总览，照常 10 秒轮播）。
- 踩坑（值得记）：第一版烧录后探针第一拍就显示 `view=0`。根因是 `online` 判定
  `millis()-lastPkt<=5000` 会让「上电头 5 秒 `lastPkt=0`」被**误判成在线**，把刚开机的设备
  错误拉去总览页 ⇒ 只插电源仍闪 6 秒总览才跳钟，等于白改。
- 修法：`online` 必须 `(lastPkt != 0) && (millis()-lastPkt<=OFFLINE_MS)`。
  只插电源时 `lastPkt` 恒为 0 ⇒ `online` 恒 false ⇒ 开机默认时钟页不被抢走。
- 二次烧录 + 验证：见上文第三节时间线 —— `view=1` 从首拍起、全程 `[1]`、`SNTP ok` 差 **0.5 s**、
  末条心跳差 **0.7 s**。

## 五、发布物同步（重要）

`烧录固件.bat` 读的是自己目录下的 `firmware\firmware.bin`。同步**前**桌面那份还是
旧的 430016 B —— 即从桌面双击烧录会把刚做的离线对时**抹掉**。现已同步，三处一致：

| 位置 | 大小 | md5 |
|---|---|---|
| `esp32/.pio/build/esp32dev/firmware.bin` | 931600 | `30e6784f…` |
| `pc/dist/pc-monitor-portable/firmware/firmware.bin` | 931600 | `30e6784f…` |
| `…\Desktop\pc-monitor-便携版\pc-monitor-portable\firmware\firmware.bin` | 931600 | `30e6784f…` |

旧固件在桌面份里留了一份 `firmware.bin.prev5`（**只留一层**，现为上一版 931568）。

## 六、还剩最后一步：真机形态验收

上面是**等价模拟**（设备仍通过 USB 连在电脑上，只是我们把 PC 数据源掐了）。
最终形态还差一眼：

> **把设备从电脑拔下来，插到 5V 充电头，看屏幕是不是显示正确时间。**

期望看到：**一开机就是时钟页**（不再有总览页「未连接」闪屏）→ 几秒后秒数开始正常走（设备联网对时后关 WiFi）。
若开机停在别的页或显示"未对时"状态词，说明现场 WiFi（2.4G）连不上，告诉我我再查。

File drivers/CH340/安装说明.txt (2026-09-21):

CH340 串口驱动 安装说明
==============================

1. 双击 CH341SER.EXE（老系统 Win7/8 需右键“以管理员身份运行”）
2. 点大按钮【安装】，提示“驱动预安装成功”即可
3. 插上开发板，拔插一次 USB 线更保险
4. 验证：右键“此电脑”→管理→设备管理器→端口(COM和LPT)，
   出现 “USB-SERIAL CH340 (COMx)” 就是装好了

来源：江苏沁恒(WCH)官方驱动，数字签名已验证有效，
兼容 32/64 位 Win7/8.1/10/11。

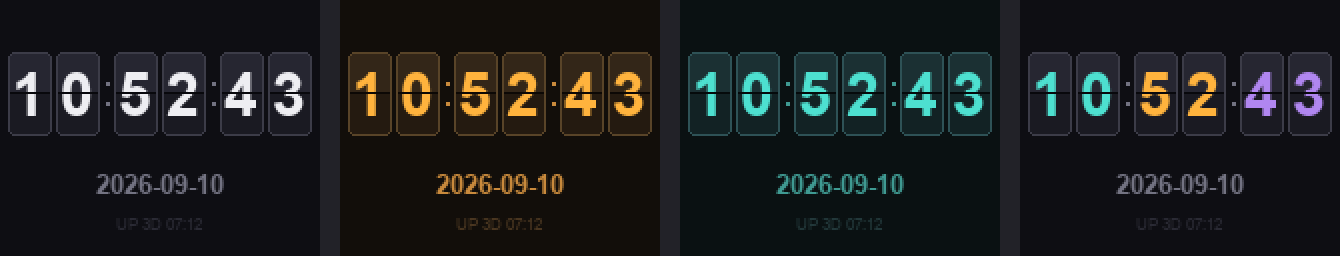
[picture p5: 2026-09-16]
docs/img/clock_themes.png

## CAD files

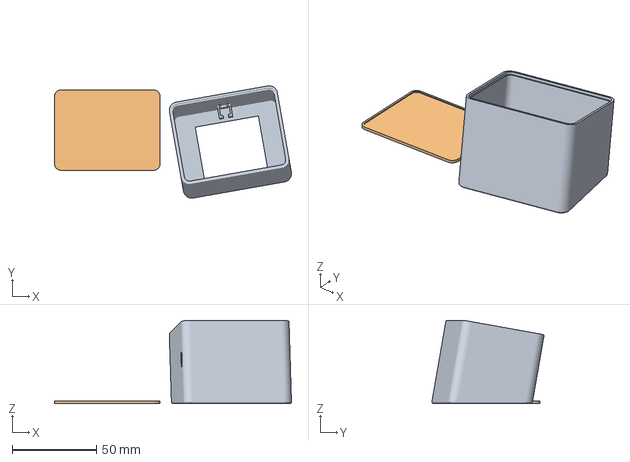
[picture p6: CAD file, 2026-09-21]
case/桌面时钟.3mf
140.5 x 66.6 x 49.4 mm
实体1
实体15

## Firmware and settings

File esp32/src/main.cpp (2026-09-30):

/* ============================================================================
   桌面电脑状态监控 · 显示端固件
   ESP32-WROOM-32 DevKit V1 (CH340C) + ST7735S 128x160 横放 = 逻辑 160x128
   数据由 PC 端 monitor.py 经 USB 串口（UART0）以 JSON 行推送，本固件只负责显示

   接线（ST7735S 模块 -> ESP32）
     VCC -> 3.3V      GND -> GND
     SCL/SCK -> 18    SDA/MOSI -> 23
     CS -> 5          DC/A0 -> 17      RES/RST -> 16
     BLK -> 4（改 PWM 调光，见亮度设置）
     MISO 不接

   轻触开关（2脚/4脚通用：一端接 GPIO，另一端接 GND；INPUT_PULLUP，按下读 LOW）
     BTN  -> 13   （唯一按键：每按一下切下一页，总览→时钟→天气循环，带幕布过渡）

   屏幕不对先改下面「屏幕微调」那五个常量，别动别的地方
   ============================================================================ */

#define LGFX_USE_V1
#include <LovyanGFX.hpp>
#include <ArduinoJson.h>
#include <math.h>
#include <string.h>    // memset（时钟页 alpha 掩码清零）
#include "netclock.h"  // 独立对时：无 PC 时用 WiFi + SNTP 取时间（凭据存 NVS，不写源码）
#include "printerlan.h" // 离线局域网打印机轮询：无 PC 时用 WiFi 直连打印机（与串口互不干涉）
#include "webui.h"     // 设备自带网页：浏览器看状态 / 填登录码（连网由 netclock 保持）
// 注：cn_font.h（年月一~十字模）随日历页一并删除 —— 需要时用 gen_cnfont.py 重新生成。

// ============================== 屏幕微调 ====================================
#define PIN_SCK   18
#define PIN_MOSI  23
#define PIN_MISO  19
#define PIN_CS     5
#define PIN_DC    17
#define PIN_RST   16
#define PIN_BLK    4

// 轻触开关：另一端接 GND，启用内部上拉，按下读 LOW
// 注意：避开 ESP32 strapping pin（0/2/5/12/15）、flash 占用（6-11）、
//      已用 SPI/背光/控制脚（4=BLK / 5=CS / 16=RST / 17=DC / 18=SCK / 23=MOSI）。
// 单按键循环切页：每按一下切到下一页（总览→时钟→天气→总览…），去抖 25ms。
// 历史包袱：OK 曾用 15（strapping）不行，改 4 又撞 BLK，最终单键定在 GPIO13。
#define PIN_BTN       13            // 唯一按键，按下=切下一页

// offset 与 memory_width/height 共同决定 CASET/RASET 的起始地址（见 Panel_LCD::setRotation）。
// 出厂几何 = 130/162 + 偏移 (0,0) → rot1 的 (colstart, rowstart) = (0, mw-pw-ox) = (0, 2)，
// 即 128 行落在 GRAM 行 [2,129]。这组值从项目第一天跑到现在，画面从未错位，别动。
#define OFFSET_X    0     // 有白边/画面偏移：调这个
#define OFFSET_Y    0     // 和这个
#define RGB_ORDER   true  // ★实测本屏必须 true：false 会走 MAD_BGR → 屏上「蓝」显示成「橙」
#define INVERT_COL  false // 整屏发黑或发白：改 true
#define SPI_FREQ    20000000  // 花屏就降到 10000000

// ---- 安装方向（外壳装反时改这里，不用拆机）--------------------------------
// 外壳把屏幕装成了 180° 倒装，需要把整屏内容也转 180°。
//
// ★为什么不直接用 lcd.setRotation(3)（两组参数都实测失败，别再回头走这条路）：
//   本屏 GRAM 是 132x162、可视 128x160，属非标准几何，180° 要靠库对地址窗口取镜像实现。
//   实测两组参数的 rot3 窗口（代入 Panel_LCD::setRotation 公式）：
//     130/162 + (0,0) → rot3 = (2, 0)，与 rot1 的 (0, 2) 不同 → 画面沿对角线错位（"斜屏"）
//     132/160 + (2,0) → rot3 = (0, 2)，与 rot1 完全相同 → 不斜了，但屏幕最上方出现一条横向乱码
//   第二组的结果说明：即使把窗口调成与 rot1 数值相同，这块屏的 MADCTL/GRAM 对应关系
//   依然无法靠库的 rotation 3 对齐。再试第三组参数是赌，不是解 —— 停在这里。
//
// ★本版改用：软件像素级 180° 翻转
//   rotation 恒为 1（完全沿用已验证正确的显示通路），在每帧绘制完成后把 sprite 缓冲
//   整体翻转 180°（行序倒置 + 行内像素倒置）再推送。
//   它不触碰任何地址窗口 / MADCTL，所以「斜屏、错位、乱码」这类地址类故障在原理上
//   不可能发生 —— 屏幕的物理行为与翻转前逐行一致。
//   代价仅为每帧一次 40KB 的内存搬运（10240 次 16bit 交换），1Hz 刷新下可忽略。
#define PANEL_FLIP_180  1   // 1 = 外壳倒装（软件翻转 180°）；0 = 正常方向
#define PANEL_ROT       1   // 固定横屏。180° 由 flipBuf180() 在像素层完成，不走 setRotation

// ============================== 网格常量 ====================================
#define SCR_W 160
#define SCR_H 128
#define HEAD_H    17      // 顶栏高度（时钟页 / 天气页仍在用）
// ★防撕裂边距（本屏的唯一硬约束，改布局前先读这段）：
//   翻转后「逻辑 y 小」= 物理顶边（SPI 推屏写入的起点，与面板扫描重叠最重）；
//   反过来「逻辑 y 大」= 物理底边。两种方向都可能撕裂，所以逻辑两端都要留纯背景带。
//   纯背景行每帧逐像素相同 → 撕裂时新旧帧一致 → 肉眼不可见。
//   若把「每秒变化的动态内容」（时钟/日期/数值）压进这两条带，撕裂立刻变成可见闪烁。
//   ⚠️ 不要再靠「把邻行复制进端点行」来兜底：邻行若含动态内容，等于把动态内容搬进撕裂带。
#define EDGE_TOP   3       // 逻辑顶部纯背景带行数（y=0..2）
#define EDGE_BOT   4       // 逻辑底部纯背景带行数（y=124..127）
#define BODY_TOP   19      // 指标行起始（逻辑 y）：上方 3~18 为「时钟带 + 凹槽分隔线」
#define ROW_H      21      // 指标行高：5 行 × 21 = 105 → 19..123，末行内容收在 y=123

// ============================== 配色（极简 · 单强调色） ======================
static constexpr uint16_t RGB(uint8_t r, uint8_t g, uint8_t b) {
  return ((r >> 3) << 11) | ((g >> 2) << 5) | (b >> 3);
}
static constexpr uint16_t swap16(uint16_t v) {
  return (uint16_t)(((v >> 8) & 0xFF) | ((v & 0xFF) << 8));
}
static const uint16_t C_BG    = RGB(0x0E, 0x0E, 0x13);  // 近黑底（TFT 背光省电）
static const uint16_t C_HEAD  = RGB(0x16, 0x16, 0x1E);  // 顶栏（极淡）
static const uint16_t C_LINE  = RGB(0x2A, 0x2A, 0x34);  // 发丝分隔线
static const uint16_t C_TXT   = RGB(0xEE, 0xEE, 0xF2);  // 主文字（近白）
static const uint16_t C_DIM   = RGB(0x73, 0x73, 0x82);  // 次要 / 注释（灰）
static const uint16_t C_ACC   = RGB(0x4D, 0xD0, 0xC4);  // 唯一强调色（清新青绿）
static const uint16_t C_WARN  = RGB(0xEF, 0x9F, 0x27);  // 负载偏高（≥60%）
static const uint16_t C_SEL   = C_ACC;                  // 选中高亮 = 强调色

// ============================== 天气页「霓虹环温」配色（E 版）================
// 与第1页(J 四环) / 第2页(C 时钟) 同族：无框近黑底 + 环仪表 + 糖果彩虹数字 + 单强调青绿。
// 设计稿 = tools/weather_jc_combo_5x.py 的 ver_e()（weather_jc_combo_5x.png 第 5 格）。
// ★ 浅底「柔雾玻璃」方案已废弃：四页里只有它是浅底，与另外三页观感割裂 —— 这是
//   结构性不匹配，靠微调色值救不回来，所以整页重做为深底。
static const uint16_t W_TOP   = C_BG;                    // 旧渐变上（已废弃，占位留名）
static const uint16_t W_BOT   = C_BG;                    // 旧渐变下（已废弃，占位留名）
static const uint16_t W_CARD  = C_BG;                    // 旧白卡已废：现仅作图标挖空底色（=页面底）
static const uint16_t W_INK   = RGB(0xE8, 0xED, 0xF2);   // 主文字 / 数字（近白，同 J_INK）
static const uint16_t W_SUB   = RGB(0x8A, 0x95, 0xA1);   // 次级标签（灰，同 J_LABEL）
static const uint16_t W_LINE  = RGB(0x2A, 0x2A, 0x34);   // 发丝分隔线
static const uint16_t W_TRACK = RGB(0x23, 0x2A, 0x32);   // 环轨道（未填充段，同 J_TRACK）
static const uint16_t W_COL_SUN   = RGB(0xFF, 0xC6, 0x5E);  // 太阳暖黄
static const uint16_t W_GLOW  = RGB(0xFF, 0xE0, 0x9A);   // 太阳外层光晕
static const uint16_t W_COL_CLOUD = RGB(0x9A, 0xA8, 0xC8);  // 云：灰蓝（深底上仍清晰）
static const uint16_t W_COL_RAIN  = RGB(0x78, 0xAA, 0xDC);  // 雨/雪：柔蓝
static const uint16_t W_BOlt  = RGB(0xF0, 0xAA, 0x5A);   // 雷电：柔橙

// RGB565 线性插值（渐变逐行用）
static inline uint16_t lerp565(uint16_t a, uint16_t b, uint8_t t) {
  int ar = (a >> 11) & 0x1F, ag = (a >> 5) & 0x3F, ab = a & 0x1F;
  int br = (b >> 11) & 0x1F, bg = (b >> 5) & 0x3F, bb = b & 0x1F;
  int r = ar + ((br - ar) * t) / 255;
  int g = ag + ((bg - ag) * t) / 255;
  int b2 = ab + ((bb - ab) * t) / 255;
  return (uint16_t)((r << 11) | (g << 5) | b2);
}
// 注：总览页已改版为「四环」仪表（见文件后部「第1页」段），其配色与阈值
//     定义在该段内（J_*）。原先的 MC_* 指标基色与 loadColor() 已无引用，删去。

// ============================== LGFX 设备 ===================================
// 自检轮播用的候选几何配置表：[memW, memH, panelW, panelH, offX, offY, rotation]
// ST7735S 128x160 斜屏几乎都出在这几个参数的组合上，轮播让用户直接指认哪组不斜
static const int CFG_N = 9;
static const int CFG_TAB[CFG_N][7] = {
  {132,162,128,160,2,1,1},
  {132,162,128,160,0,0,1},
  {132,162,128,160,0,3,1},
  {132,162,128,160,2,3,1},
  {132,162,128,160,1,2,1},
  {130,162,128,160,0,0,1},   // 5 = 出厂几何 rot1（与 LGFX 构造函数当前值一致）
  {132,160,128,160,0,0,1},   // 6
  {132,160,128,160,2,0,3},   // 7 = 出厂几何 rot3（与第 5 项配对：两者都应不斜才算正确）
  {132,162,128,160,2,1,0},
};
static int gCfg = 0;
static int gW = 160, gH = 128;

class LGFX : public lgfx::LGFX_Device {
  lgfx::Panel_ST7735S _panel;
  lgfx::Bus_SPI       _bus;

public:
  LGFX() {
    {
      auto cfg = _bus.config();
      cfg.spi_host   = VSPI_HOST;
      cfg.spi_mode   = 0;
      cfg.freq_write = SPI_FREQ;
      cfg.freq_read  = 8000000;
      cfg.spi_3wire  = false;
      cfg.use_lock   = true;
      cfg.dma_channel = 1;
      cfg.pin_sclk = PIN_SCK;
      cfg.pin_mosi = PIN_MOSI;
      cfg.pin_miso = PIN_MISO;
      cfg.pin_dc   = PIN_DC;
      _bus.config(cfg);
      _panel.setBus(&_bus);
    }
    {
      auto cfg = _panel.config();
      cfg.pin_cs    = PIN_CS;
      cfg.pin_rst   = PIN_RST;
      cfg.pin_busy  = -1;
      cfg.panel_width  = 128;
      cfg.panel_height = 160;
      cfg.memory_width  = 130;   // 配 OFFSET_X=0 → rot1 的 rowstart = 130-128-0 = 2（长期验证值）
      cfg.memory_height = 162;   // 出厂值；rotation 恒为 1，180° 由 flipBuf180() 完成
      cfg.offset_x     = OFFSET_X;
      cfg.offset_y     = OFFSET_Y;
      cfg.offset_rotation = 0;
      cfg.readable = false;
      cfg.invert   = INVERT_COL;
      cfg.rgb_order = RGB_ORDER;
      cfg.dlen_16bit = false;
      cfg.bus_shared = false;
      _panel.config(cfg);
    }
    setPanel(&_panel);
  }

  // 自检轮播：切到第 idx 组几何配置并重新初始化屏幕
  void applyCfg(int idx) {
    int i = ((idx % CFG_N) + CFG_N) % CFG_N;
    auto cfg = _panel.config();
    cfg.memory_width  = CFG_TAB[i][0];
    cfg.memory_height = CFG_TAB[i][1];
    cfg.panel_width   = CFG_TAB[i][2];
    cfg.panel_height  = CFG_TAB[i][3];
    cfg.offset_x      = CFG_TAB[i][4];
    cfg.offset_y      = CFG_TAB[i][5];
    cfg.offset_rotation = 0;
    _panel.config(cfg);
    init();                        // 重复 init 会按新配置重写 MADCTL/CASET/RASET
    setRotation(CFG_TAB[i][6]);
    fillScreen(C_BG);
  }
};

static LGFX lcd;
static LGFX_Sprite sprite(&lcd);
#include "weather_cn.h" // 天气页中文点阵字模（晴/阴/雨/雪…），须放在 sprite 声明之后
#include "cn_city.h"    // 城市名中文点阵字模（地名常用字），同样须在 sprite 之后
#include "mc_theme.h"   // 总览页《我的世界》主题：5x7 点阵字 + 方块图标（纯 ASCII，不需中文字库）
#include "clock_fonts.h" // 时钟页圆润数字掩码（多字体 4-bit alpha，长按按键循环切换）

// ============================== 数据 ========================================
struct Stats {
  int   cpu   = -1;
  int   mem   = -1;
  float memGB = -1;
  int   cpuT  = -999;
  int   gpu   = -1;
  int   gpuT  = -999;
  float upKB  = 0;
  float dnKB  = 0;
  int   disk  = -1;
  float dskFreeGB = -1;
  char  time[8]   = "--:--";
  char  date[8]   = "";
  char  uptime[10]= "";
  int   year  = 0;   // 时钟页离线走时用：PC 下发的完整日期
  int   month = 0;
  int   day   = 0;
  int   sec   = 0;   // 秒（驱动时钟页秒针环 / 冒号闪烁）

  // 天气页（PC 端 monitor.py 经 Open-Meteo 下发，无数据时为未就绪）
  bool   wHave = false;   // 是否已拿到过一次天气
  float  wTemp = 0;      // 当前温度 °C
  int    wCode = -1;      // WMO 天气代码
  float  wFeel = 0;      // 体感温度 °C
  int    wHum  = -1;     // 相对湿度 %
  float  wWind = 0;      // 风速 km/h
  float  wHi   = 0;      // 当日最高温 °C
  float  wLo   = 0;      // 当日最低温 °C
  char   wCity[24] = "";   // 城市名（中文 UTF-8，优先显示）
  char   wCityEn[24] = ""; // 城市名（英文 ASCII，字库缺字时回退）
};
static Stats   st;

// 打印机实况：PStat 结构定义见 printerlan.h（串口与局域网两种来源共用）。
// 定义在 main.cpp（printerlan.cpp 通过 extern 引用），渲染层只读它、不感知来源。
PStat pr[2];
static bool    hasData = false;
static uint32_t lastPkt = 0;
static volatile bool newData = false;   // 收到一帧完整有效数据就置位

// ---- 前向声明：这些函数定义在文件后部，提前声明供渲染/解析调用 ----
static void render();
static void drawPrinterPage(int idx);
void drawSelfTestPattern();
static int daysInMonth(int y, int m);
// 收包/错包计数（串口解析共用，定义在此以便前置使用）
static uint32_t rxOk = 0, rxBad = 0;

// ---- 内部时钟：PC 关机后由 ESP32 自己走时，不再依赖电脑 ----
// 时间有两个来源，优先级 PC > NTP：
//   1) PC 在线：串口每帧带真实时间 → syncClockFromPC() 逐帧对齐（零漂移）
//   2) PC 不在线：netclock 模块用 WiFi + SNTP 取一次标准时间（见 netclock.h），
//      之后由 tickClock() 按 millis() 流逝自走，每 6 小时重校一次
// 因此设备脱离电脑后（哪怕重新上电、甚至从没接过电脑）也能显示正确时间。
static int      gClkY = 0, gClkM = 0, gClkD = 0;   // 年/月/日
static int      gClkH = 0, gClkMi = 0, gClkS = 0;  // 时/分/秒
static uint32_t gClkMs = 0;                        // 上次从 PC 同步时间时的 millis()
static bool     gClkSynced = false;                // 是否已拿到过一次有效时间
static const uint32_t OFFLINE_MS = 5000;           // 超过这么久没收帧 = PC 已离线
static bool     gOfflineHold = false;              // 已进入「离线值守」（停在时钟页当钟用），PC 回来才解除
static bool     gFirstOnlineDone = false;           // 上电后首次确认「插着电脑在线」→ 从开机默认的时钟页升级到总览页

// ============================== 12x12 矢量图标 ==============================
enum { IC_CLOCK, IC_CHIP, IC_RAM, IC_NET, IC_GPU, IC_DISK };

static void drawIcon(int id, int x, int y, uint16_t c) {
  switch (id) {
    case IC_CLOCK:
      sprite.drawCircle(x + 6, y + 6, 5, c);
      sprite.drawLine(x + 6, y + 6, x + 6, y + 3, c);
      sprite.drawLine(x + 6, y + 6, x + 9, y + 6, c);
      sprite.fillRect(x + 5, y + 0, 2, 1, c);
      break;
    case IC_CHIP:
      sprite.drawRect(x + 2, y + 2, 8, 8, c);
      sprite.fillRect(x + 4, y + 4, 4, 4, c);
      sprite.fillRect(x + 4, y + 0, 1, 2, c);
      sprite.fillRect(x + 7, y + 0, 1, 2, c);
      sprite.fillRect(x + 4, y + 10, 1, 2, c);
      sprite.fillRect(x + 7, y + 10, 1, 2, c);
      sprite.fillRect(x + 0, y + 4, 2, 1, c);
      sprite.fillRect(x + 0, y + 7, 2, 1, c);
      sprite.fillRect(x + 10, y + 4, 2, 1, c);
      sprite.fillRect(x + 10, y + 7, 2, 1, c);
      break;
    case IC_RAM:
      sprite.drawRect(x + 1, y + 3, 10, 6, c);
      sprite.fillRect(x + 3, y + 5, 1, 2, c);
      sprite.fillRect(x + 5, y + 5, 1, 2, c);
      sprite.fillRect(x + 7, y + 5, 1, 2, c);
      sprite.fillRect(x + 2, y + 9, 1, 2, c);
      sprite.fillRect(x + 5, y + 9, 1, 2, c);
      sprite.fillRect(x + 8, y + 9, 1, 2, c);
      break;
    case IC_NET:
      sprite.drawLine(x + 6, y + 1, x + 6, y + 11, c);
      sprite.fillTriangle(x + 6, y + 1, x + 3, y + 5, x + 9, y + 5, c);
      sprite.fillTriangle(x + 6, y + 11, x + 3, y + 7, x + 9, y + 7, c);
      break;
    case IC_GPU:
      sprite.drawRect(x + 1, y + 3, 10, 7, c);
      sprite.drawCircle(x + 4, y + 6, 2, c);
      sprite.drawCircle(x + 8, y + 6, 2, c);
      sprite.fillRect(x + 3, y + 10, 6, 1, c);
      break;
    case IC_DISK:
      sprite.drawRoundRect(x + 1, y + 3, 10, 6, 1, c);
      sprite.fillRect(x + 3, y + 5, 4, 1, c);
      sprite.fillRect(x + 3, y + 7, 4, 1, c);
      sprite.fillCircle(x + 9, y + 6, 1, c);
      break;
  }
}

// ============================== 绘制工具 ====================================
// Font2 是 BMPfont、Font0 是 GLCDfont，两者类型不同，不能写成三元表达式，
// 必须分开调用 setFont(const IFont*) 重载
static void pickFont(int fontH) {
  if (fontH > 12) sprite.setFont(&lgfx::fonts::Font2);
  else            sprite.setFont(&lgfx::fonts::Font0);
}
static void txtRight(const char* s, int right, int centerY, int fontH, uint16_t color, uint16_t bg) {
  pickFont(fontH);
  sprite.setTextColor(color, bg);
  sprite.setCursor(right - sprite.textWidth(s), centerY - fontH / 2);
  sprite.print(s);
}
static void txtLeft(const char* s, int left, int centerY, int fontH, uint16_t color, uint16_t bg) {
  pickFont(fontH);
  sprite.setTextColor(color, bg);
  sprite.setCursor(left, centerY - fontH / 2);
  sprite.print(s);
}
static void txtCenter(const char* s, int cx, int centerY, int fontH, uint16_t color, uint16_t bg) {
  pickFont(fontH);
  sprite.setTextColor(color, bg);
  sprite.setCursor(cx - sprite.textWidth(s) / 2, centerY - fontH / 2);
  sprite.print(s);
}

// 大号文本（Font2 × size 放大），用于重点数字
static void txtBig(const char* s, int cx, int cy, int size, uint16_t color) {
  sprite.setFont(&lgfx::fonts::Font2);
  sprite.setTextSize(size);
  sprite.setTextColor(color, C_BG);
  sprite.setCursor(cx - sprite.textWidth(s) / 2, cy - (16 * size) / 2);
  sprite.print(s);
  sprite.setTextSize(1);
}

// 速率格式化：>=1024 KB/s 显示 M，否则 K
static void fmtRate(float kb, char* out, size_t n) {
  if (kb < 0)          snprintf(out, n, "--");
  else if (kb >= 1024) snprintf(out, n, "%.1fM", kb / 1024.0f);
  else                 snprintf(out, n, "%.0fK", kb);
}

// ---- 软件 180° 翻转（外壳倒装用）------------------------------------------
// 为什么不用 lcd.setRotation(3)：见文件顶部 PANEL_FLIP_180 处的说明（两组参数实测均失败）。
// 这里对 sprite 的 16bit 缓冲做「行序倒置 + 行内像素倒置」= 整幅 180° 旋转。
//
// 三点必须守住：
//  1) 只搬 16bit 元素、不拆元素内部字节 —— 缓冲是 swap565 字节序，拆字节会红蓝互换。
//  2) 按 sprite.width() 逐行处理，不假设整块缓冲连续无行间距。
//  3) 只能在「本帧绘制已全部完成、即将 push」时调用；调用后缓冲内容已变，
//     若同一帧再画东西或再翻转一次，画面就会被转回/画错位置。
static void flipBuf180() {
  if (!PANEL_FLIP_180) return;
  uint16_t* buf = (uint16_t*)sprite.getBuffer();
  const int W = sprite.width();
  const int H = sprite.height();
  if (!buf || W <= 0 || H <= 0 || W > SCR_W) return;

  static uint16_t line[SCR_W];          // 单行暂存 320B，避免逐像素三重交换
  for (int y = 0; y < H / 2; ++y) {
    uint16_t* a = buf + (size_t)y * W;
    uint16_t* b = buf + (size_t)(H - 1 - y) * W;
    for (int x = 0; x < W; ++x) line[x] = a[x];          // 暂存上半行
    for (int x = 0; x < W; ++x) a[x] = b[W - 1 - x];     // 下半行倒序搬上去
    for (int x = 0; x < W; ++x) b[W - 1 - x] = line[x];  // 上半行倒序搬下来
  }
  if (H & 1) {                                           // 奇数高度时中间行需自反
    uint16_t* m = buf + (size_t)(H / 2) * W;
    for (int x = 0; x < W / 2; ++x) { uint16_t t = m[x]; m[x] = m[W - 1 - x]; m[W - 1 - x] = t; }
  }

  // ★不要在这里做任何「端点补偿」——曾经加过两版都没用，第二版还制造了新故障：
  //   旧 v1：把最外 1 行涂成 gBgColor → 该行原本是头栏色，涂完露出一条异色横线；
  //   旧 v2：把紧邻端点的内侧行整行复制进端点行 → 内侧行若是「每秒变化的数值」
  //          （总览页 y=126 正是 DSK 副值字形底行），等于把动态内容搬进撕裂带，
  //          底部于是出现一条随数值跳变的短横线（"最左下方闪烁/乱码"的真身）。
  //   正确做法是让逻辑两端各留若干行**纯背景**（见文件顶部 EDGE_TOP/EDGE_BOT 说明）：
  //   背景行每帧逐像素恒等，撕裂时新旧帧相同 → 天然不可见，不需要任何补偿代码。
}

// 统一的「推屏」出口：翻页过渡期间 gPush=false，只画进 sprite 不推送，
// 由过渡逻辑在 sprite 上叠加幕布后再手动 push。
static bool gPush = true;
static void pushScreen() {
  if (!gPush) return;
  flipBuf180();
  sprite.pushSprite(0, 0);
}

// ============================== 按键 ========================================
// 单按键两种手势：
//   短按（按住 <600ms 后松开）→ 循环切页
//   长按（按住 >=600ms）      → 循环切换时钟页数字字体（用于在设备上现场比对字形）
// 判定走 25ms 去抖后的 stable 电平，全程非阻塞（loop 每 2ms 调一次）。
struct Btn {
  uint8_t pin;
  bool raw;         // 最近一次 raw 读
  bool stable;      // 去抖后的稳定电平（LOW=按下）
  uint32_t dbT;     // 上次 raw 翻转时刻
  uint32_t downT;   // 按下沿（stable 变 LOW）时刻，用于长按计时
  bool longFired;   // 本次按住是否已触发长按（防止松手时再补一次短按）
};
static Btn BTN;
// 单按键：按下沿 → 切下一页（循环）
static bool evNext = false;
static bool evFont = false;   // 长按 → 切换时钟页字体
static const uint32_t BTN_LONG_MS = 600;

static void btnSetup() {
  pinMode(PIN_BTN, INPUT_PULLUP);
  BTN.pin = PIN_BTN;
  BTN.raw = digitalRead(PIN_BTN);
  BTN.stable = BTN.raw;
  BTN.dbT = 0;
  BTN.downT = 0;
  BTN.longFired = false;
}
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
void loop() {
  pumpSerial();
  btnPoll();
  tickClock();   // 离线时内部时钟继续走时
  uint32_t now = millis();

  // 在线 / 离线判定与翻页策略：
  // ・开机默认就是时钟页（curView 初值 VIEW_CLOCK）→ 只插电源不开机即直接是钟，没有「未连接」闪屏。
  // ・上电后首次收到 PC 数据帧 ⇒ 确认插着电脑在线 ⇒ 从时钟页升级到总览页开始正常轮播。
  // ・运行中断流（PC 离线）超过 OFFLINE_MS ⇒ 回到时钟页当钟用并锁定，直到 PC 重新连上。
  // ★ online 必须「确实收到过帧」才算在线：lastPkt 初值 0 会让「上电头 5 秒」被误判为在线
  //   （millis()-0<=5000），从而把刚开机的设备错误地拉去总览页。只插电源不开机时，
  //   lastPkt 一直为 0 ⇒ online 恒为 false ⇒ 开机默认时钟页不会被抢走，直接就是钟。
  bool online = (lastPkt != 0) && (millis() - lastPkt <= OFFLINE_MS);
  if (online && !gFirstOnlineDone) {
    gFirstOnlineDone = true;                       // 首帧到达：插着电脑，升级到总览页
    if (curView != VIEW_OVERVIEW) goPage(VIEW_OVERVIEW);
  }
  // 离线局域网轮询：在线时它自动让位给串口（不动 WiFi），离线时它用 WiFi 直连打印机。
  plPoll(now, online);

  if (!online) {
    bool lanPrinter = plCfgEnabled(0) || plCfgEnabled(1);
    if (!lanPrinter) {
      // 没有离线打印机 → 守时钟（原行为：开机默认已在时钟页，运行中电脑断开也回到时钟当钟用）
      if (!gOfflineHold && now > OFFLINE_MS + 1000) {
        gOfflineHold = true;
        if (curView != VIEW_CLOCK) goPage(VIEW_CLOCK);
      }
    } else {
      // 有离线打印机 → 解锁，允许在「时钟 / 打印机页」之间轮播，不再强制停在时钟
      gOfflineHold = false;
    }
  } else if (gOfflineHold) {
    gOfflineHold = false;                          // PC 重新连上 → 回到总览页继续监控
    if (curView != VIEW_OVERVIEW) goPage(VIEW_OVERVIEW);
  }

  // 独立对时：PC 在线且已有时间时 pcTime=true → 模块完全不碰 WiFi；
  // 只有「没有 PC 时间源」时才联网取时间（对上一次之后每 6 小时才重校）。
  bool pcTime = online && gClkSynced;
  netPoll(now, pcTime);
  int ny, nmo, nd, nh, nmi, ns;
  if (netTakeTime(ny, nmo, nd, nh, nmi, ns)) setClock(ny, nmo, nd, nh, nmi, ns);

  // 网页服务：处理浏览器请求。放在翻页过渡的 return 之前，保证每轮 loop 都被调到，
  // 否则幕布动画那 170ms 里浏览器请求会被推迟。handleClient 处理完一个请求即返回。
  webPoll(now);

  // 翻页幕布过渡：用 BG 幕布从左锚定向右展开，露出已画好的新页
  if (transActive) {
    if (now - transStart >= TRANS_MS) {
      gPush = true;
      transActive = false;
      render();                       // 收尾：推最终帧
    } else {
      gPush = false;
      render();                       // 把新页画进 sprite（不推送）
      int w = (int)(SCR_W * (1.0f - (float)(now - transStart) / TRANS_MS));
      // 180° 软件翻转会把缓冲左右镜像 → 幕布画在逻辑右侧，屏上才会出现在左侧，
      // 观感仍是「幕布自左向右收缩、新页自右向左展开」，与翻转前一致。
      sprite.fillRect(SCR_W - w, 0, w, SCR_H, C_BG);   // 幕布：已展开部分露出新页
      flipBuf180();
      sprite.pushSprite(0, 0);
    }
    delay(2);
    return;
  }

  if (evNext) handleUi();

  // 自动轮播：PC 在线时每 10 秒切下一页（总览→时钟→天气→总览），本页停留 10 秒。
  // 手动按键切页会把 pageDwellT 清零，故刚切过去不会被立刻带走。
  // 离线（PC 关机）不轮播总览/天气（它们需要 PC 数据）—— 但若配置了离线打印机，
  // 则在「时钟 + 已启用打印机页」之间轮播，让打印机页也能脱离电脑自动显示。
  if (online && now - pageDwellT >= AUTO_PAGE_MS) {
    goPage((ViewPage)(((int)curView + 1) % N_PAGES));
  } else if (!online && (plCfgEnabled(0) || plCfgEnabled(1)) && now - pageDwellT >= AUTO_PAGE_MS) {
    goPage(nextOfflinePage(curView));
  }

  if (uiState == ST_MON && curView == VIEW_CLOCK) {
    updateFlipDigits(true);   // 在线=随帧同步；离线=内部时钟走时，秒变即翻页
    // 时钟页：翻页动画期间按 25fps 重绘，静止时跟随数据帧（1Hz）
    bool anim = false;
    for (int i = 0; i < 6; i++) if (FD[i].anim) { anim = true; break; }
    if (anim) {
      if (now - lastClockDraw >= FLIP_FPS) { lastClockDraw = now; render(); }
    } else if (newData || (now - lastClockDraw > 600)) {
      newData = false;
      lastClockDraw = now;
      render();
    }
  } else {
    // 只有「来了新数据」或「距上次重绘满刷新间隔」才刷屏。
    // 数据是 1Hz 的，无脑重绘会让大半的 SPI 传输在推重复画面。
    bool need = newData || (now - lastDraw >= gRefreshMs);
    if (need) {
      newData  = false;
      lastDraw = now;
      render();
    }
  }

  // 心跳：3 秒一行，报当前页 / 累计收帧 / 坏帧 / 是否有数据 / 剩余内存。
  // 用来在「屏幕不亮或不更新」时区分「没收到数据」和「收到了但没画出来」。
  static uint32_t lastHb = 0;
  if (now - lastHb >= 3000) {
    lastHb = now;
    // net= 与 t= 是「设备脱离电脑后到底有没有时间」的客观凭据（不必靠看屏）
    Serial.printf("[HB] view=%d rx=%lu bad=%lu data=%d net=%s t=%02d:%02d:%02d heap=%u\n",
                  (int)curView, (unsigned long)rxOk, (unsigned long)rxBad,
                  (int)hasData, netStatusText(),
                  gClkH, gClkMi, gClkS, (unsigned)ESP.getFreeHeap());
  }

  delay(2);   // 让出 CPU，避免 loop 空转把 IDLE 饿死触发任务看门狗
}

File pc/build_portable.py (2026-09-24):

#!/usr/bin/env python3
# -*- coding: utf-8 -*-
"""
把采集端和看门狗打包成免 Python 的 exe，给没装 Python 的电脑用。

产物
    dist/pc-monitor-portable/
        monitor.exe     采集端（无窗口，登录自启、常驻、自连自重）
        flash.exe       烧录器（console 窗口）
        安装.bat        注册 monitor.exe 的登录自启任务并立即启动
        卸载.bat        删除计划任务并结束采集
        暂停采集.bat    停任务+结束采集，把 COM 口让出来（烧录固件前用）
        恢复采集.bat    恢复任务并重新拉起采集
        烧录固件.bat    暂停→烧录→恢复
        使用说明.txt

说明（2026-09-19 改）
    已去掉 watcher 看门狗。monitor 自身就会常驻等待板子、自动连、断线重连、
    串口号变了重扫；看门狗唯一不可替代的作用「开机把它拉起来」改由任务计划的
    登录自启（AtLogOn + 崩溃自动重启）承担，少一个常驻进程。

为什么要这套东西
    另一台电脑没装 Python 时，脚本版跑不起来，也装不了依赖。
    PyInstaller 把解释器 + 依赖 + 脚本打进单个 exe，拷过去就能用。

两个必须注意的点
    1. 用 --windowed：常驻程序不能有控制台窗口，否则桌面上一直挂着黑框。
       windowed 模式下 sys.stdout 为 None，脚本已内置兜底把输出写进日志文件。
    2. 打包后 __file__ 指向临时解压目录（_MEIPASS），日志会写进去然后随进程
       退出丢失。所以 monitor.py / flash.py 里统一用 app_dir() 定位目录。

依赖（打包机必须装全，缺一会打出坏 exe）
    pip install pyinstaller esptool psutil pyserial nvidia-ml-py
    - esptool   → flash.exe 的运行时依赖（动态 import，静态分析扫不到）
    - pynvml(nvidia-ml-py) → monitor.exe 读 GPU（monitor.py 里 try import）

用法
    python build_portable.py
"""

import glob
import os
import shutil
import subprocess
import sys
import time

HERE = os.path.dirname(os.path.abspath(__file__))
OUT_DIR = os.path.join(HERE, "dist", "pc-monitor-portable")

# PyInstaller 对中文路径不总是友好（踩过链接器打不开文件的问题），
# 中间产物一律放纯 ASCII 目录，打完再拷回来。
BUILD_ROOT = os.path.join(os.environ.get("TEMP", r"C:\Windows\Temp"), "pcmonitor_build")

# (脚本, 产物名, 窗口模式, 额外参数)
#   常驻的 monitor 必须 windowed，否则桌面一直挂黑框；
#   flash 反过来要 console——烧录时得让用户在窗口里看到进度和报错。
TARGETS = (
    # monitor 里 printers 走 try-import（可选功能），显式声明避免被静态分析漏掉，
    # 否则打包出来的 exe 会缺 printers 模块、打印机页永远「无数据」。
    # paho.mqtt.client 在 printers.py 的 AnycubicLAN._session() 函数内 import，
    # 静态分析同样扫不到，必须一并 hidden-import（2026-09-24 加局域网 MQTT 后端）。
    ("monitor.py", "monitor", "windowed",
     ["--hidden-import", "printers", "--hidden-import", "paho.mqtt.client",
      "--hidden-import", "paho.mqtt.properties", "--hidden-import",
      "paho.mqtt.subscribeoptions"]),
    ("flash.py", "flash", "console",
     # esptool 用 importlib 动态加载各芯片 target，静态分析扫不到，必须整个收进来
     ["--collect-submodules", "esptool", "--collect-data", "esptool"]),
)

# 任务名。旧版是 PCMonitorWatch（看门狗），新版只跑 monitor.exe。
# 安装/卸载脚本的清理列表同时覆盖两个名字，方便从旧版平滑迁移。
TASK_NAME = "PCMonitor"
LEGACY_TASK_NAME = "PCMonitorWatch"


def say(msg=""):
    print(msg, flush=True)


def build_one(script, name, mode="windowed", extra=None):
    """打一个 exe，返回是否成功。"""
    cmd = [
        sys.executable, "-m", "PyInstaller",
        "--onefile",
    ]
    if mode == "windowed":
        cmd.append("--windowed")
    cmd += [
        "--clean",
        "--noconfirm",
        "--name", name,
        "--distpath", os.path.join(BUILD_ROOT, "dist"),
        "--workpath", os.path.join(BUILD_ROOT, "work"),
        "--specpath", os.path.join(BUILD_ROOT, "spec"),
        # monitor.py 里 pynvml 是在函数内 try import，静态分析可能扫不到
        "--hidden-import", "pynvml",
        "--hidden-import", "serial.tools.list_ports",
        "--exclude-module", "tkinter",
        "--log-level", "WARN",
    ]
    cmd += list(extra or [])
    cmd.append(script)
    say("  打包 %s ..." % name)
    r = subprocess.run(cmd, cwd=HERE, capture_output=True, text=True)
    if r.returncode != 0:
        say("  失败：")
        say((r.stdout or "")[-2000:])
        say((r.stderr or "")[-2000:])
        return False
    return True


def stop_running():
    """结束产物目录里正在跑的实例。

    Windows 上 exe 运行期间文件被锁，覆盖复制会 PermissionError，
    rmtree 也会失败。重打包前必须先停掉。
    """
    killed = []
    try:
        import psutil
        for p in psutil.process_iter(["pid", "name"]):
            try:
                if (p.info.get("name") or "").lower() in ("monitor.exe", "watcher.exe"):
                    p.kill()
                    killed.append(p.info["name"])
            except Exception:
                pass
    except ImportError:
        for n in ("monitor.exe", "watcher.exe"):
            subprocess.run(["taskkill", "/f", "/im", n], capture_output=True)

    if killed:
        say("  已结束运行中的 %s（否则文件被锁，覆盖不了）" % ", ".join(sorted(set(killed))))
        time.sleep(2)


def restart_task():
    """打包杀掉了实例，装完顺手把采集任务拉回来。起不来也不拦，提示手动恢复。"""
    try:
        r = subprocess.run(
            ["powershell.exe", "-NoProfile", "-NonInteractive", "-Command",
             "Start-ScheduledTask -TaskName '%s' -ErrorAction Stop;"
             "(Get-ScheduledTask -TaskName '%s').State" % (TASK_NAME, TASK_NAME)],
            capture_output=True, text=True, timeout=60)
        out = (r.stdout or "").strip()
        state = out.splitlines()[-1] if out else ""
        if state:
            say("  采集任务已重新拉起：%s" % state)
            return
    except Exception:
        pass
    say("  采集任务没能自动拉起，双击「安装.bat」恢复")


def copy_firmware():
    """把编译产物和 boot_app0 拷进 firmware/。

    boot_app0.bin 不在工程目录里，在 Arduino 框架包里，得单独找——
    它是 OTA 数据区的初始内容，漏烧会让板子卡在启动循环。
    """
    build = os.path.normpath(os.path.join(HERE, "..", "esp32", ".pio", "build", "esp32dev"))
    out = os.path.join(OUT_DIR, "firmware")
    os.makedirs(out, exist_ok=True)

    cands = sorted(glob.glob(os.path.join(
        os.path.expanduser("~"), ".platformio", "packages",
        "framework-arduinoespressif32*", "tools", "partitions", "boot_app0.bin")))

    pairs = (
        (os.path.join(build, "bootloader.bin"), "bootloader.bin"),
        (os.path.join(build, "partitions.bin"), "partitions.bin"),
        (os.path.join(build, "firmware.bin"), "firmware.bin"),
        (cands[0] if cands else None, "boot_app0.bin"),
    )

    ok = True
    for src, name in pairs:
        if not src or not os.path.isfile(src):
            say("  缺 %s（%s）" % (name, src or "没找到路径"))
            ok = False
            continue
        dst = os.path.join(out, name)
        shutil.copy2(src, dst)
        say("  firmware\\%s  %.0f KB" % (name, os.path.getsize(dst) / 1024))
    return ok


def make_bat(name, body):
    """bat 用 UTF-8 存，开头 chcp 65001 切代码页，中文才不会乱码。"""
    path = os.path.join(OUT_DIR, name)
    with open(path, "w", encoding="utf-8") as f:
        f.write("\ufeff@echo off\nchcp 65001 >nul\n" + body)
    return path
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

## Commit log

2026-09-16 Initial commit: ESP32 desktop PC status monitor (ST7735S + LovyanGFX)
2026-09-21 Add CH340/CH341 USB-serial driver; bundle netclock offline-clock module and UI design generators; refresh OSS packaging
2026-09-21 Add one-click CH340 driver installer: pnputil pre-register for plug-and-play + raw signed driver files
2026-09-21 Add 3D-printed enclosure model (桌面时钟.3mf)
    [桌面时钟.3mf]
2026-09-21 Add real-product photos of the 3D-printed build; note case/ and drivers/ in repo tree
2026-09-21 Fix weather fetch on some networks: force IPv4 (avoid IPv6 stall on home broadband) + auto-detect local proxy ports (Clash/v2ray not set as system proxy); add diagnose_weather.py
    [diagnose_weather.py, monitor.py]
2026-09-24 Add 3D printer live status: two new device pages (Creality / Anycubic)
    - esp32/src/main.cpp: add VIEW_PRINTER1/2 (N_PAGES 3 -> 5), PStat struct and
    a drawPrinterPage() rendering name + state header, three rings
    (HOT / BED / PRG), a progress bar and the current file name; parse the
    p1_*/p2_* fields from the serial JSON frame.
    - pc/printers.py: new backend that polls two printers and normalises both to
    p1_*/p2_* keys. Creality via local Moonraker (:7125, no account);
    Anycubic via Anycubic Cloud (XX-Token). Force-IPv4 + local-proxy fallback,
    same network path as the weather module. --dump saves the raw JSON for
    field-mapping fixes.
    - pc/monitor.py: start PrinterManager in a backgr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
    [main.cpp, monitor.py, printers.py]
2026-09-24 Fix printers.py config path under PyInstaller; ship printers.json.example
    - pc/printers.py: resolve printers.json / printer_debug.json via a frozen-aware
    _app_dir() (sys.executable when frozen) instead of __file__. In a one-file
    PyInstaller build __file__ points into _MEIPASS, so the portable exe could
    never find the config next to it and printers stayed disabled silently.
    - pc/build_portable.py: declare --hidden-import printers (the import is inside a
    try/except, easy for static analysis to miss), copy printers.json.example into
    the portable folder, and document the printer feature in 使用说明.txt.
    [build_portable.py, printers.py]
2026-09-24 build_portable: verify esptool is installed before packaging flash.exe
    flash.py loads esptool via importlib, so PyInstaller needs --collect-submodules
    esptool. If the packaging environment has no esptool, the resulting flash.exe
    fails at runtime with "ModuleNotFoundError: No module named 'esptool'" while
    the build itself still reports success. Add an upfront import check and list
    the full packaging dependency set in the docstring.
    [build_portable.py]
2026-09-24 打印机页统一中文化 + 串口配网工具 + 操作手册
    - 打印机两页 UI 统一：环标签中文（热端/热床/进度）+ 顶栏状态中文化（打印中/空闲/未连接）
    - 字模表扩 6 字（打印空闲连接），gen_weather_cn.py 同步
    - 修复 Creality Moonraker 后端（printers.json.example 演示 IP 改 192.168.1.50）
    - 新增 pc/send_cmd.py 串口配网工具（发 WIFI:/NET? 并抓取设备回复的 IP）
    - 新增 docs/操作手册.html（送人自装指南）与 docs/纵维立方局域网接入指南.md
    - esp32 新增 webui（网页配网/状态页）
    - export_opensource.py 排除 build_send/dist_send 构建产物，放行 .html 与 .example
    [build_portable.py, gen_weather_cn.py, main.cpp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]
2026-09-24 清理废弃文件：cn_font.h 及其测试/预览脚本（日历页删除后已无引用）
    - esp32/src/cn_font.h：日历页字模，2026-09-19 删页后无 include（需要时 gen_cnfont.py 可重新生成）
    - esp32/tools/test_cnfont.py、render_calendar_preview.py：仅服务于已删除的日历页
    - main.cpp 注释同步更新
2026-09-30 双源互不干涉：PC 离线时固件 WiFi 直连打印机（真机验证通过）
    - printerlan.h/.cpp：PC 在线=串口喂数，离线=固件 WiFi 直连（Creality Moonraker HTTP / Anycubic MQTT-TLS-AES），渲染层只读统一 PStat，由在线状态单一门控天然互斥
    - partitions.csv：自定义 3MB app 分区（离线轮询的 flash 前提），platformio.ini 同步启用
    - netclock：新增独立 gLanHold 保持位；轮询加 WiFi 就绪门控（开机即有配置时避免 lwIP assert）
    - 修复：sign 取 MD5(token[:16])、纪元毫秒时间戳、b64 解码改查函数式、/info/report 主题匹配（strstr）、report 状态逻辑对齐 PC 端、deviceId 缓冲 40、HTT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
    [partitions.csv]
2026-09-30 修正 .gitignore：行内注释导致负模式失效，prebuilt 四件套此前未入库
